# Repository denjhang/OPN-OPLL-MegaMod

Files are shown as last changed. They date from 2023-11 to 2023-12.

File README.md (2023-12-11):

# OPN-OPLL-MegaMod
 OPN+OPLL MegaMod, the latest hardware version has passed hardware verification
 
# 2023.11.25
OPN+OPLL MegaMod v0.3 have passed hardware testing and all functions have been verified. The old version has many problems and is not recommended.  
## OPN+OPLL MegaMod v0.3 includes the following features:
1. OPN and OPLL chips can support playing VGM music of PC-9801-26K, MSX-Music, ZX-Spectrum, and Atari ST. Software driver support provided by natalie.  
2. A typical dual op amp driven by a single 5V (take NE5532 as an example), it works well and sounds loud. It is especially effective for the sound amplification function of OPLL.  
3. Independent volume adjustment knob. Supports adjusting the volume of OPN and SSG, as well as the overall volume of the mixer. The volume of OPLL cannot be adjusted because the volume of OPLL itself is too small. This function is completely normal, and the volumes of each channel will not interfere with each other when adjusting the volume.  
4. SSG can be configured with stereo sound. Use three three-position toggle switches to independently control the stereo channels of each SSG. This function is completely normal and will not affect the volume of OPN and OPLL.
5. SSG stereo mixing circuit. This part is based on the ZX-Spectrum's golden ratio mixing circuit, but I modified the resistor values to provide a more stereo effect.  
6. OPN and OPLL monophonic mixing circuit. Since there is no such combination of using OPN.FM+OPLL at the same time, OPN and OPLL configurable stereo make little sense. A mono mix is used here, which means the left and right channels sound the same.  
7. Compatible with OPLL cloning chip. Just remove the pull-down resistors of the MO and RO analog audio tree pool of YM2413.  
8. Compatible with U3567, UM3567, YM2413-F and YM2413B-F, using a simple conversion board to implement.  

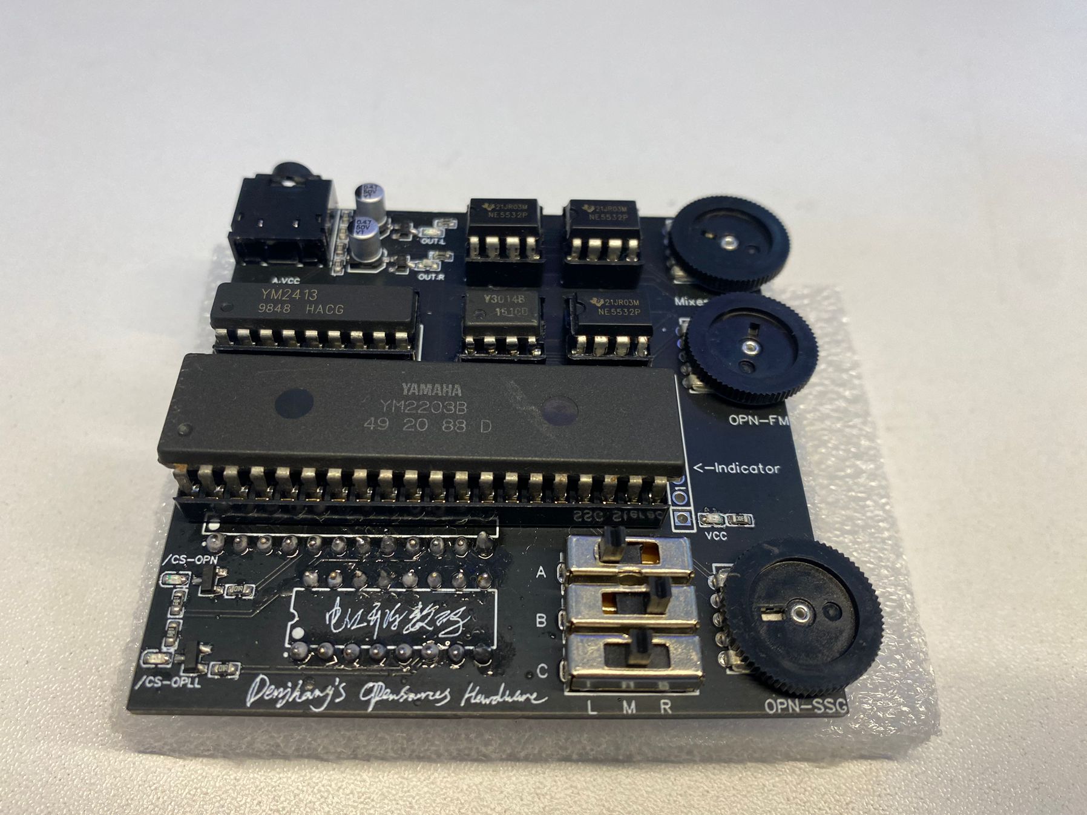
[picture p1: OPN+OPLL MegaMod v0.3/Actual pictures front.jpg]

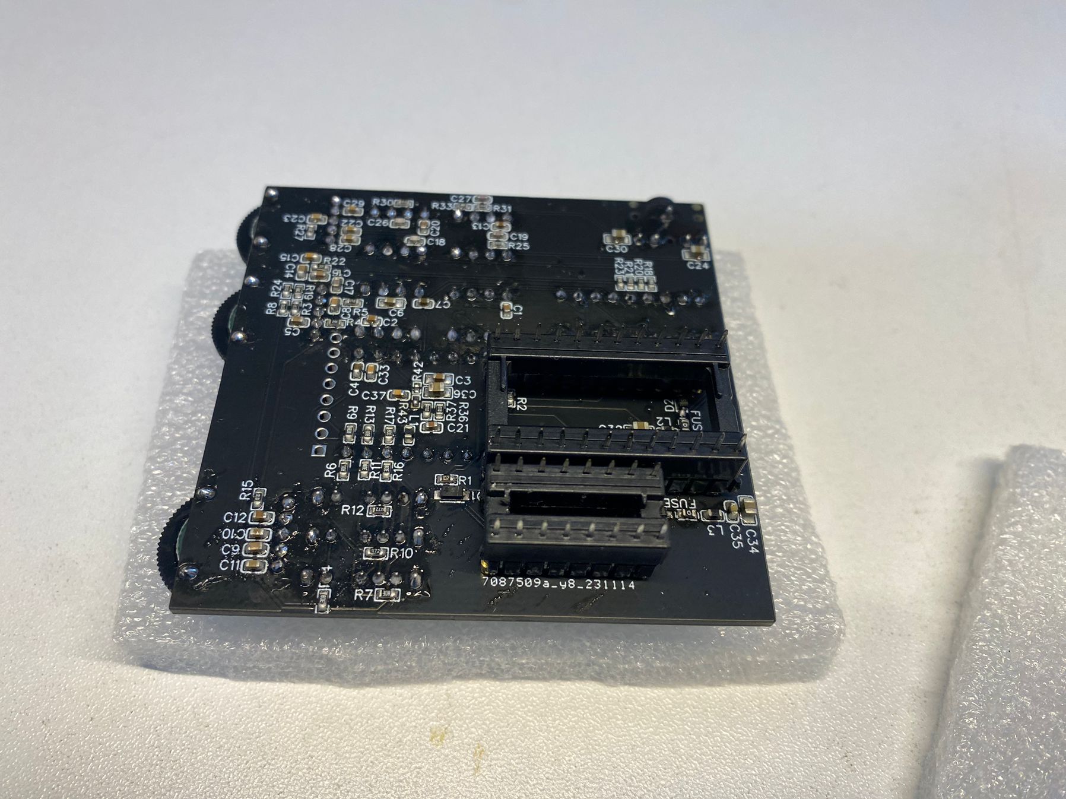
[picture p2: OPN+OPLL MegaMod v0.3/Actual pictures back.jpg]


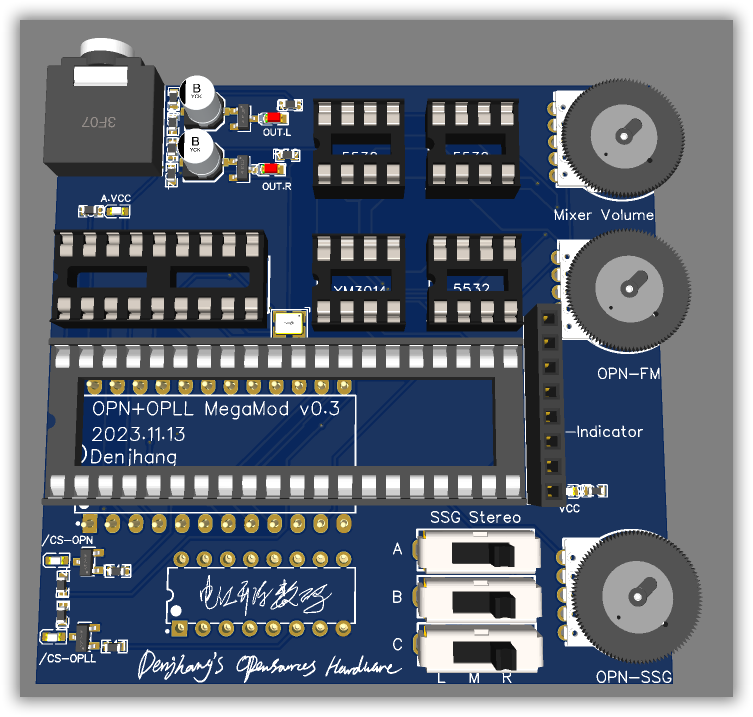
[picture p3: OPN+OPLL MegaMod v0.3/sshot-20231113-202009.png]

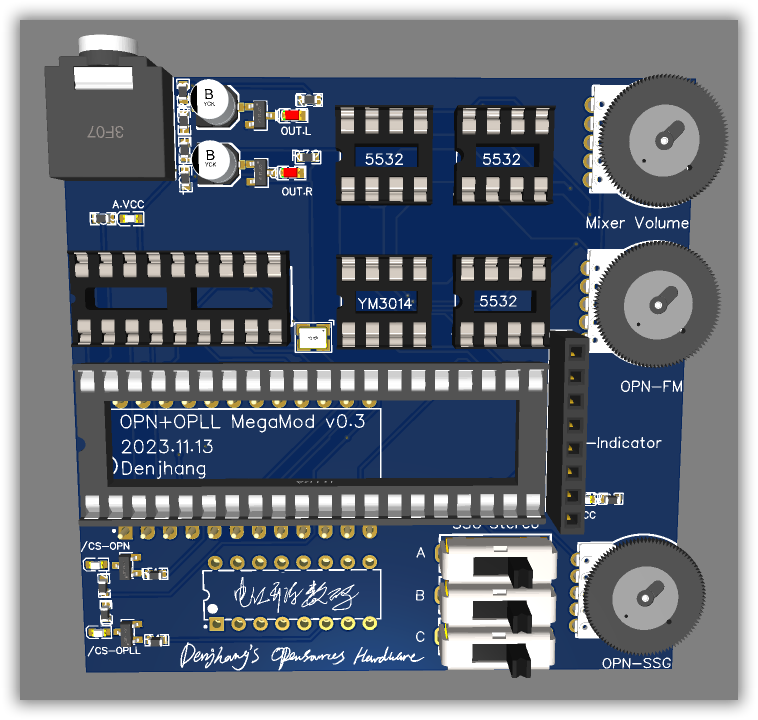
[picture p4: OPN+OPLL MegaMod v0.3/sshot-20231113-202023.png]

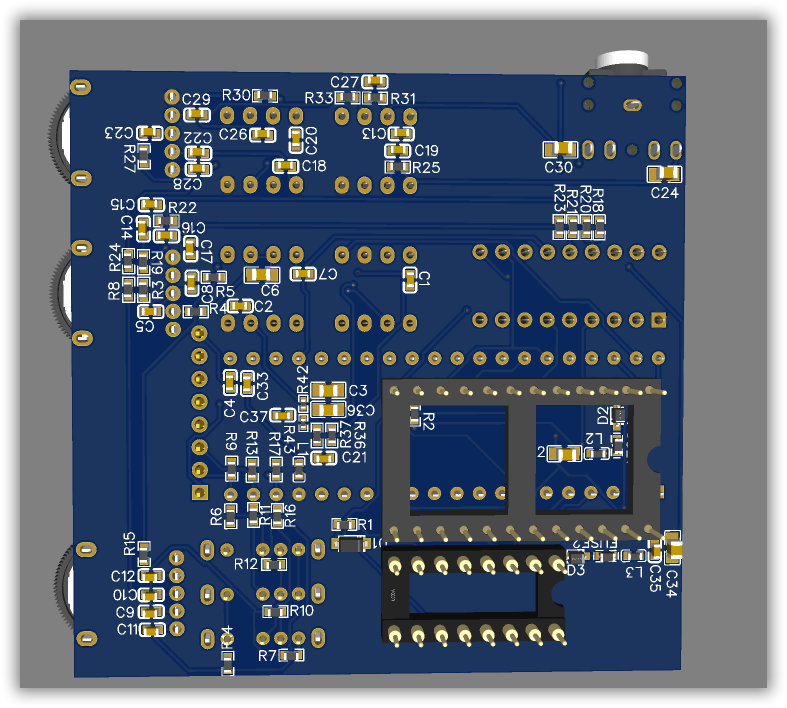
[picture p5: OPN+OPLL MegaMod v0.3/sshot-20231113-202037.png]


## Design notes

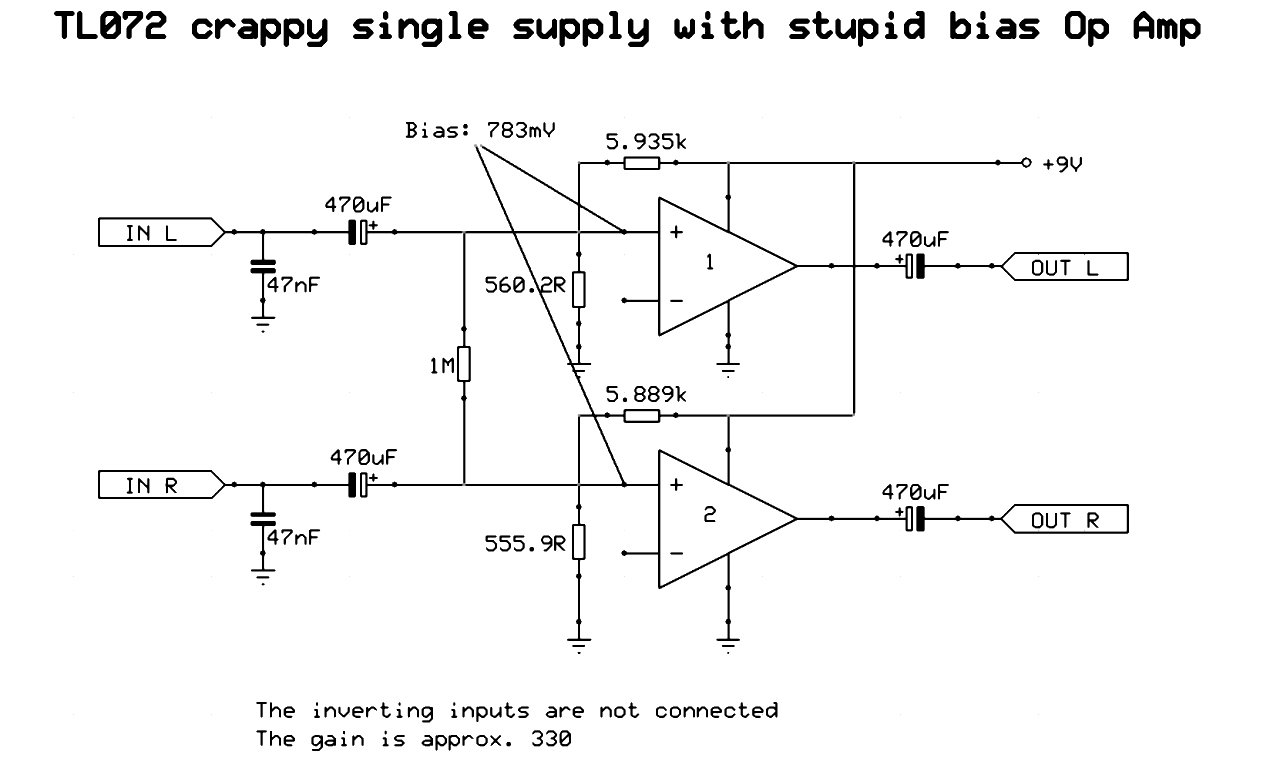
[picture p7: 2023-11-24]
资料2/TL072__Schematic_01.png

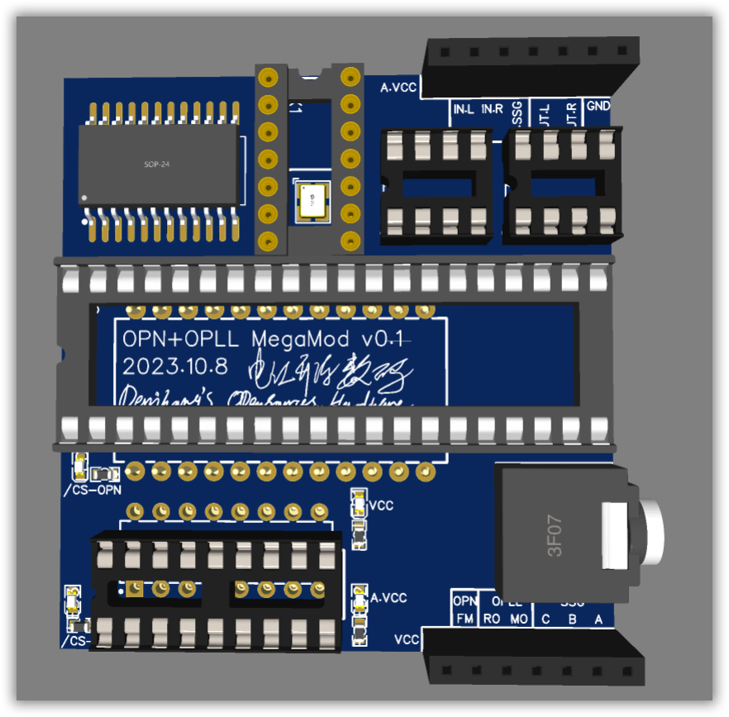
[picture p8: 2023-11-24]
pics/sshot-20231008-172234.png

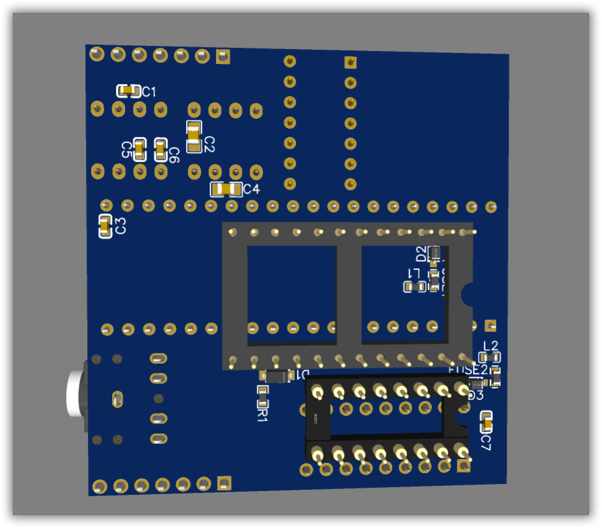
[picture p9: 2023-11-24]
pics/sshot-20231008-172720.png

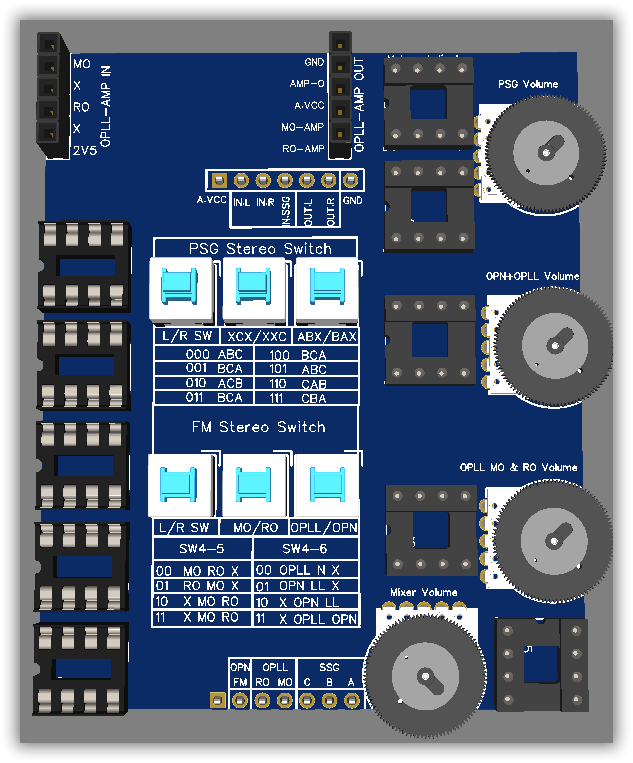
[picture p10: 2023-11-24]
OPN+OPLL AMP v0.1/pics/sshot-20231009-220135.png

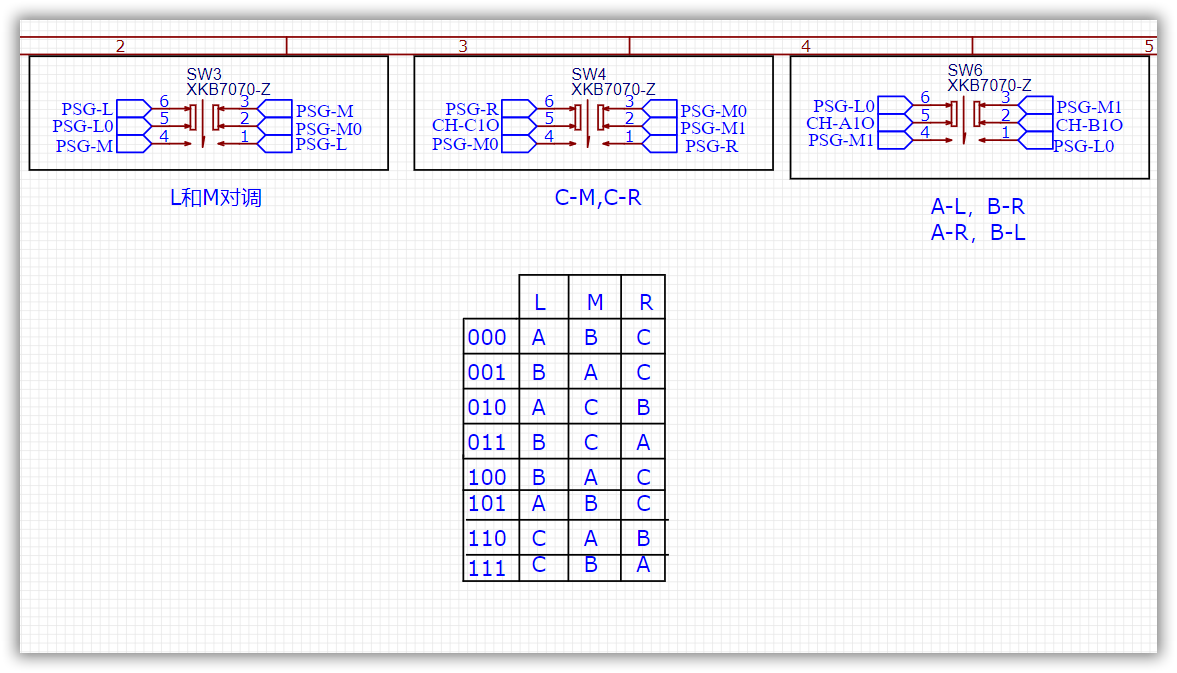
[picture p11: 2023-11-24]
pics/sshot-20231009-154045.png

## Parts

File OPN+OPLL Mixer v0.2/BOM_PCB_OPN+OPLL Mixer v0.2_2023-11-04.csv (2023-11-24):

ID | Name | Designator | Footprint | Quantity | Manufacturer Part | Manufacturer | Supplier | Supplier Part | Price
1 | 2k7 | R11,R9,R14,R17,R25,R27,R30,R32,R33,R34,R16,R18 | R0603 | 12
2 | 100k | R44,R6,R43,R1 | R0603 | 4
3 | PZ254V-11-07P | H1,H2 | HDR-TH_7P-P2.54-V-M | 2 | PZ254V-11-07P | XFCN(兴飞) | LCSC | C492406 | 0.2121
4 | 100Ω | L1 | L0603 | 1 | CBW160808U102T | FH | LCSC | C50069 | 0.0296
5 | 1N5819WS | D1 | SOD-323_L1.8-W1.3-LS2.5-RD | 1 | 1N5819WS | Hottech(合科泰) | LCSC | C191023 | 0.0759
6 | PPTC0.5A/24V 自恢复保险丝-0603 | FUSE1 | F0603 | 1 | PPTC0.5A/24V 自恢复保险丝-0603 | null | LCSC | C9900007586
7 | 2k2 | R26,R31,R5,R10,R15,R3 | R0603 | 6
8 | 4k7 | R28,R29,R12,R13 | R0603 | 4
9 | 120p | C9,C13,C22,C24,C1,C5 | C0603 | 6
10 | 1u | C10,C15,C2,C7 | C0603 | 4
11 | 1u | C11,C16,C3,C8 | C0805 | 4
12 | 22pf | C12,C14 | C0603 | 2
13 | 47p | C17 | C0603 | 1
14 | 2.2u | C18,C19 | C0603 | 2
15 | 4.7u | C20,C21 | C0603 | 2
16 | 47u | C23,C25 | C0805 | 2
17 | 100u | C26 | C1206 | 1
18 | 20k | R4,R7,R36,R37,R39,R40,R41 | R0603 | 7
19 | 22k | R8,R20,R22,R24,R2 | R0603 | 5
20 | 51k | R19,R21,R23,R35,R38 | R0603 | 5
21 | 1.5n | C4,C6 | C0603 | 2
22 | SS-22D07 | SW7 | SW-TH_SS-22D07 | 1 | SS-22D07 | ReliaPro | LCSC | C34982 | 0.241
23 | 10k | R42 | R0603 | 1
24 | HX SS13D07VG3-DJ | SW1,SW2,SW3,SW4,SW5,SW6 | SW-TH_SS13D07VG4 | 6 | HX SS13D07VG3 | hanxia(韩下) | LCSC | C5149830 | 0.1776
25 | NE5532-DJ | U3,U4,U5,U6 | DIP-8-DJ | 4 | NE5532P | TI | LCSC | C5326 | 2.91
26 | PM254-1-08-Z-8.5 | U1,U2 | HDR-TH_8P-P2.54-V-F | 2 | PM254-1-08-Z-8.5 | HCTL(华灿天禄) | LCSC | C2897371 | 0.8039
27 | 圆盘双联电位器10K | RV1,RV2,RV4,RV3 | RES-TH_RK10J12E002L | 4
28 | LED0603 | LED1,LED2 | LED0603-RD | 2 | GBG-C192KRKT | GBG | LCSC | C2892154 | 0.0219

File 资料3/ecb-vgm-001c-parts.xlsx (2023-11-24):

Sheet: Sheet1
"Ref","Qnty","Value","Cmp name","Footprint","Description","Vendor"
"C1, C2, C3, C4, C7, C8, C10, C18, C19, C22, C23, C28, C29, C50, ","14","0.1uF","C","Capacitor_THT:C_Disc_D7.0mm_W2.5mm_P5.00mm"," | Unp | olarized capacitor",""
"C5, C20, C21, C34, C35, ","5","470uF","CP","Capacitor_THT:CP_Radial_D8.0mm_P2.50mm","Polarized capacitor",""
"C6, ","1","100uF","CP","Capacitor_THT:CP_Radial_D5.0mm_P2.50mm","Polarized capacitor",""
"C24, C25, ","2","100uF","CP","Capacitor_THT:CP_Radial_D8.0mm_P2.50mm","Polarized capacitor",""
"C26, C27, C36, C37, C39, C41, ","6","10uF","C","Capacitor_THT:CP_Radial_D5.0mm_P2.50mm","Unpolarized capacitor",""
"C30, C31, ","2","470pF","C","Capacitor_THT:C_Disc_D3.8mm_W2.6mm_P2.50mm","Unpolarized capacitor",""
"C32, C33, ","2","1uF","C","Capacitor_THT:C_Disc_D7.0mm_W2.5mm_P5.00mm","Unpolarized capacitor",""
"C38, C46, ","2","220pF","C","Capacitor_THT:C_Disc_D3.8mm_W2.6mm_P2.50mm","Unpolarized capacitor",""
"C40, C47, ","2","1uF","C","Capacitor_THT:CP_Radial_D5.0mm_P2.50mm","Unpolarized capacitor",""
"C42, C43, C44, C45, ","4","5.6nF","C","Capacitor_THT:C_Disc_D3.8mm_W2.6mm_P2.50mm","Unpolarized capacitor",""
"CX1, CX2, ","2","0.1uF","C","Capacitor_THT:C_Disc_D7.0mm_W2.5mm_P5.00mm","Unpolarized capacitor",""
"H1, ","1","MountingHole","MountingHole","MountingHole:MountingHole_5mm","Mounting Hole without connection",""
"J1, ","1","Barrel_Jack","Barrel_Jack","Connector_BarrelJack:BarrelJack_Horizontal","DC Barrel Jack",""
"J3, ","1","Conn_01x04","Conn_01x04","TerminalBlock:TerminalBlock_bornier-4_P5.08mm","Generic connector, single row, 01x04, script | ge | nerated (kicad-library-utils/schlib/autogen/connector/)",""
"JP1, ","1","Jumper_3_Open","Jumper_3_Open","Connector_PinHeader_2.54mm:PinHeader_1x03_P2.54mm_Vertical","Jumper, 3-pole, both ope | n", | ""
"L1, L2, ","2","33uH","INDUCTOR","Inductor_THT:L_Axial_L6.6mm_D2.7mm_P10.16mm_Horizontal_Vishay_IM-2","Inductor symbol for simulat | ion | only",""
"R1, R3, R4, R5, R6, R7, ","6","2K2","R","Resistor_THT:R_Axial_DIN0207_L6.3mm_D2.5mm_P10.16mm_Horizontal","Resistor",""
"R2, R13, ","2","51K","R","Resistor_THT:R_Axial_DIN0207_L6.3mm_D2.5mm_P10.16mm_Horizontal","Resistor",""
"R8, R9, R14, R15, R16, R17, ","6","10K","R","Resistor_THT:R_Axial_DIN0207_L6.3mm_D2.5mm_P10.16mm_Horizontal","Resistor",""
"R10, R11, ","2","10R","R","Resistor_THT:R_Axial_DIN0207_L6.3mm_D2.5mm_P10.16mm_Horizontal","Resistor",""
"R12, R20, ","2","47K","R","Resistor_THT:R_Axial_DIN0207_L6.3mm_D2.5mm_P10.16mm_Horizontal","Resistor",""
"R18, R19, ","2","33K","R","Resistor_THT:R_Axial_DIN0207_L6.3mm_D2.5mm_P10.16mm_Horizontal","Resistor",""
"RN1, ","1","22K","R_Network08","Resistor_THT:R_Array_SIP9","8 resistor network, star topology, bussed resistors, small symbol",""
"RV1, ","1","10K","R_POT_Dual","Potentiometer_THT:Potentiometer_Alps_RK097_Dual_Horizontal","Dual potentiometer",""
"RV2, RV3, ","2","10K","R_POT_TRIM","Potentiometer_THT:Potentiometer_Bourns_3339P_Vertical","Trim-potentiometer",""
"SW1, ","1","ADDR","Conn_02x06_Odd_Even","Connector_PinHeader_2.54mm:PinHeader_2x06_P2.54mm_Vertical","Generic connector, double r | ow, | 02x06, odd/even pin numbering scheme (row 1 odd numbers, row 2 even numbers), script generated (kicad-library-utils/schlib/autogen/connector/)",""
"SW3, ","1","N8VEM/KONTRON","Conn_01x03","Jumper:SolderJumper-3_P1.3mm_Open_RoundedPad1.0x1.5mm_NumberLabels","Generic connector, | sin | gle row, 01x03, script generated (kicad-library-utils/schlib/autogen/connector/)",""
"U1, ","1","74LS245","74LS245","Package_DIP:DIP-20_W7.62mm","Octal BUS Transceivers, 3-State outputs",""
"U2, U8, ","2","74LS241","74LS241","Package_DIP:DIP-20_W7.62mm","Octal Buffer and Line Driver With 3-State Output, complementary e | nab | les, non-inverting outputs",""
"U3, ","1","74LS688","74LS688","Package_DIP:DIP-20_W7.62mm","8-bit magnitude comparator",""
"U4, ","1","YM2612","YM2612-Audio","Package_DIP:DIP-24_W15.24mm","",""
"U5, ","1","TL072","TL072","Package_DIP:DIP-8_W7.62mm","Dual Low-Noise JFET-Input Operational Amplifiers, DIP-8/SOIC-8",""
"U6, ","1","74LS74","74LS74","Package_DIP:DIP-14_W7.62mm","Dual D Flip-flop, Set & Reset",""
"U10, ","1","74LS139","74LS139","Package_DIP:DIP-16_W7.62mm","Dual Decoder 1 of 4, Active low outputs",""
"U18, U19, ","2","SN76489","SN76489","Package_DIP:DIP-16_W7.62mm","",""
"U20, ","1","C96ABC","C96ABC","library:C96ABCMC","Connector Europe, 96 contacts, ranges A,B,C",""
"U21, U22, ","2","LM386","LM386","Package_DIP:DIP-8_W7.62mm","Low Voltage Audio Power Amplifier, DIP-8/SOIC-8/SSOP-8",""
"X1, ","1","3.57595Mhz","CXO_DIP8","Oscillator:Oscillator_DIP-8","Crystal Clock Oscillator, DIP8-style metal package",""
"X2, ","1","7.6Mhz","CXO_DIP8","Oscillator:Oscillator_DIP-8","Crystal Clock Oscillator, DIP8-style metal package",""

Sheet: Sheet2
Ref | Qnty | Value | Cmp name | Footprint | Description | Vendor
C1, C2, C3, C4, C7, C8, C10, C18, C19, C22, C23, C28, C29, C50, | 14 | 0.1uF | C | Capacitor_THT:C_Disc_D7.0mm_W2.5mm_P5.00mm | Unpolarized capacitor
C5, C20, C21, C34, C35, | 5 | 470uF | CP | Capacitor_THT:CP_Radial_D8.0mm_P2.50mm | Polarized capacitor
C6, | 1 | 100uF | CP | Capacitor_THT:CP_Radial_D5.0mm_P2.50mm | Polarized capacitor
C24, C25, | 2 | 100uF | CP | Capacitor_THT:CP_Radial_D8.0mm_P2.50mm | Polarized capacitor
C26, C27, C36, C37, C39, C41, | 6 | 10uF | C | Capacitor_THT:CP_Radial_D5.0mm_P2.50mm | Unpolarized capacitor
C30, C31, | 2 | 470pF | C | Capacitor_THT:C_Disc_D3.8mm_W2.6mm_P2.50mm | Unpolarized capacitor
C32, C33, | 2 | 1uF | C | Capacitor_THT:C_Disc_D7.0mm_W2.5mm_P5.00mm | Unpolarized capacitor
C38, C46, | 2 | 220pF | C | Capacitor_THT:C_Disc_D3.8mm_W2.6mm_P2.50mm | Unpolarized capacitor
C40, C47, | 2 | 1uF | C | Capacitor_THT:CP_Radial_D5.0mm_P2.50mm | Unpolarized capacitor
C42, C43, C44, C45, | 4 | 5.6nF | C | Capacitor_THT:C_Disc_D3.8mm_W2.6mm_P2.50mm | Unpolarized capacitor
CX1, CX2, | 2 | 0.1uF | C | Capacitor_THT:C_Disc_D7.0mm_W2.5mm_P5.00mm | Unpolarized capacitor
H1, | 1 | MountingHole | MountingHole | MountingHole:MountingHole_5mm | Mounting Hole without connection
J1, | 1 | Barrel_Jack | Barrel_Jack | Connector_BarrelJack:BarrelJack_Horizontal | DC Barrel Jack
J3, | 1 | Conn_01x04 | Conn_01x04 | TerminalBlock:TerminalBlock_bornier-4_P5.08mm | Generic connector, single row, 01x04, script generated (kicad-library-utils/schlib/autogen/connector/)
JP1, | 1 | Jumper_3_Open | Jumper_3_Open | Connector_PinHeader_2.54mm:PinHeader_1x03_P2.54mm_Vertical | Jumper, 3-pole, both open
L1, L2, | 2 | 33uH | INDUCTOR | Inductor_THT:L_Axial_L6.6mm_D2.7mm_P10.16mm_Horizontal_Vishay_IM-2 | Inductor symbol for simulation only
R1, R3, R4, R5, R6, R7, | 6 | 2K2 | R | Resistor_THT:R_Axial_DIN0207_L6.3mm_D2.5mm_P10.16mm_Horizontal | Resistor
R2, R13, | 2 | 51K | R | Resistor_THT:R_Axial_DIN0207_L6.3mm_D2.5mm_P10.16mm_Horizontal | Resistor
R8, R9, R14, R15, R16, R17, | 6 | 10K | R | Resistor_THT:R_Axial_DIN0207_L6.3mm_D2.5mm_P10.16mm_Horizontal | Resistor
R10, R11, | 2 | 10R | R | Resistor_THT:R_Axial_DIN0207_L6.3mm_D2.5mm_P10.16mm_Horizontal | Resistor
R12, R20, | 2 | 47K | R | Resistor_THT:R_Axial_DIN0207_L6.3mm_D2.5mm_P10.16mm_Horizontal | Resistor
R18, R19, | 2 | 33K | R | Resistor_THT:R_Axial_DIN0207_L6.3mm_D2.5mm_P10.16mm_Horizontal | Resistor
RN1, | 1 | 22K | R_Network08 | Resistor_THT:R_Array_SIP9 | 8 resistor network, star topology, bussed resistors, small symbol
RV1, | 1 | 10K | R_POT_Dual | Potentiometer_THT:Potentiometer_Alps_RK097_Dual_Horizontal | Dual potentiometer
RV2, RV3, | 2 | 10K | R_POT_TRIM | Potentiometer_THT:Potentiometer_Bourns_3339P_Vertical | Trim-potentiometer
SW1, | 1 | ADDR | Conn_02x06_Odd_Even | Connector_PinHeader_2.54mm:PinHeader_2x06_P2.54mm_Vertical | Generic connector, double row, 02x06, odd/even pin numbering scheme (row 1 odd numbers, row 2 even numbers), script generated (kicad-library-utils/schlib/autogen/connector/)
SW3, | 1 | N8VEM/KONTRON | Conn_01x03 | Jumper:SolderJumper-3_P1.3mm_Open_RoundedPad1.0x1.5mm_NumberLabels | Generic connector, single row, 01x03, script generated (kicad-library-utils/schlib/autogen/connector/)
U1, | 1 | 74LS245 | 74LS245 | Package_DIP:DIP-20_W7.62mm | Octal BUS Transceivers, 3-State outputs
U2, U8, | 2 | 74LS241 | 74LS241 | Package_DIP:DIP-20_W7.62mm | Octal Buffer and Line Driver With 3-State Output, complementary enables, non-inverting outputs
U3, | 1 | 74LS688 | 74LS688 | Package_DIP:DIP-20_W7.62mm | 8-bit magnitude comparator
U4, | 1 | YM2612 | YM2612-Audio | Package_DIP:DIP-24_W15.24mm
U5, | 1 | TL072 | TL072 | Package_DIP:DIP-8_W7.62mm | Dual Low-Noise JFET-Input Operational Amplifiers, DIP-8/SOIC-8
U6, | 1 | 74LS74 | 74LS74 | Package_DIP:DIP-14_W7.62mm | Dual D Flip-flop, Set & Reset
U10, | 1 | 74LS139 | 74LS139 | Package_DIP:DIP-16_W7.62mm | Dual Decoder 1 of 4, Active low outputs
U18, U19, | 2 | SN76489 | SN76489 | Package_DIP:DIP-16_W7.62mm
U20, | 1 | C96ABC | C96ABC | library:C96ABCMC | Connector Europe, 96 contacts, ranges A,B,C
U21, U22, | 2 | LM386 | LM386 | Package_DIP:DIP-8_W7.62mm | Low Voltage Audio Power Amplifier, DIP-8/SOIC-8/SSOP-8
X1, | 1 | 3.57595Mhz | CXO_DIP8 | Oscillator:Oscillator_DIP-8 | Crystal Clock Oscillator, DIP8-style metal package
X2, | 1 | 7.6Mhz | CXO_DIP8 | Oscillator:Oscillator_DIP-8 | Crystal Clock Oscillator, DIP8-style metal package

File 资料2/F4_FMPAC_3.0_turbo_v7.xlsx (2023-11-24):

Reference | Value | Footprint | Datasheet | Cdad
C1, C2 | 2.2uF25v | MSXmakers:CP_tumbado | ~ | 2
C3, C4, C22, C23 | 22pF | Capacitor_THT:C_Disc_D4.3mm_W1.9mm_P5.00mm | -- valores mixtos -- | 4
C5, C6 | 47uF 16v | MSXmakers:CP_tumbado | ~ | 2
C7, C12 | 1uF 25v | MSXmakers:CP_tumbado | ~ | 2
C8, C10, C11, C13, C15, C17, C18 | 100nF | Capacitor_THT:C_Disc_D4.3mm_W1.9mm_P5.00mm |  | 7
C9 | 10uF 16V | MSXmakers:CP_tumbado | ~ | 1
C14, C24 | 330pF | Capacitor_THT:C_Disc_D4.3mm_W1.9mm_P5.00mm | -- valores mixtos -- | 2
C16 | 68pF | Capacitor_THT:C_Disc_D4.3mm_W1.9mm_P5.00mm |  | 1
CN1 | DIP40 MB CONN | Package_DIP:DIP-40_W15.24mm_Socket |  | 1
CN2 | DIP8 MB CONN | Package_DIP:DIP-8_W7.62mm_Socket | http://ww1.microchip.com/downloads/en/DeviceDoc/21314g.pdf | 1
D1, D2 | 1N4148 | Diode_THT:D_DO-35_SOD27_P7.62mm_Horizontal | -- valores mixtos -- | 2
D3 | LED | LED_THT:LED_D3.0mm | ~ | 1
D4 | LED 3mm | LED_THT:LED_D3.0mm | ~ | 1
J1 | clock_sel MB/JP | Connector_PinSocket_2.54mm:PinSocket_1x02_P2.54mm_Vertical | ~ | 1
J2 | slot clock | Connector_PinSocket_2.54mm:PinSocket_1x02_P2.54mm_Vertical | ~ | 1
J3 | Clocksel | Connector_PinHeader_2.54mm:PinHeader_1x03_P2.54mm_Vertical | ~ | 1
JP1 | Conn_01x05 | MSXmakers:Eletechsup_DD1718PA | ~ | 1
Q1 | BS170 | Package_TO_SOT_THT:TO-92L | https://www.onsemi.com/pub/Collateral/BS170-D.PDF | 1
R1, R2, R9, R10 | 22k | Resistor_THT:R_Axial_DIN0204_L3.6mm_D1.6mm_P7.62mm_Horizontal |  | 4
R3, R22 | 100k | Resistor_THT:R_Axial_DIN0204_L3.6mm_D1.6mm_P7.62mm_Horizontal | -- valores mixtos -- | 2
R4-R8 | 2k2 | Resistor_THT:R_Axial_DIN0204_L3.6mm_D1.6mm_P7.62mm_Horizontal |  | 5
R11 | 68R | Resistor_THT:R_Axial_DIN0204_L3.6mm_D1.6mm_P7.62mm_Horizontal |  | 1
R12, R13 | 100R | Resistor_THT:R_Axial_DIN0204_L3.6mm_D1.6mm_P7.62mm_Horizontal |  | 2
R14 | 1k | Resistor_THT:R_Axial_DIN0204_L3.6mm_D1.6mm_P7.62mm_Horizontal |  | 1
R15 | 4k7 | Resistor_THT:R_Axial_DIN0204_L3.6mm_D1.6mm_P7.62mm_Horizontal |  | 1
R16, R24 | 560R | Resistor_THT:R_Axial_DIN0204_L3.6mm_D1.6mm_P7.62mm_Horizontal | -- valores mixtos -- | 2
R18 | 22K | Resistor_THT:R_Axial_DIN0204_L3.6mm_D1.6mm_P7.62mm_Horizontal | ~ | 1
R20 | 10M | Resistor_THT:R_Axial_DIN0204_L3.6mm_D1.6mm_P7.62mm_Horizontal | ~ | 1
R21 | 220R | Resistor_THT:R_Axial_DIN0204_L3.6mm_D1.6mm_P7.62mm_Horizontal | ~ | 1
R23 | 47R | Resistor_THT:R_Axial_DIN0204_L3.6mm_D1.6mm_P7.62mm_Horizontal | ~ | 1
S1 | turbo_on | Connector_PinHeader_2.54mm:PinHeader_1x02_P2.54mm_Vertical | ~ | 1
SJ3 | SJ | Connector_PinHeader_2.54mm:PinHeader_1x02_P2.54mm_Vertical |  | 1
U1 | 74HC04 | MSXmakers:DIP-14c_W7.62mm_LongPads | https://assets.nexperia.com/documents/data-sheet/74HC_HCT04.pdf | 1
U2 | 74HC153 | MSXmakers:DIP-16c_W7.62mm_Socket_LongPads | http://www.ti.com/lit/gpn/sn74LS153 | 1
U3 | 74HC175 | MSXmakers:DIP-16c_W7.62mm_Socket_LongPads | http://www.ti.com/lit/gpn/sn74LS175 | 1
U4 | YM2413 | MSXmakers:DIP-18c_W7.62mm_LongPads |  | 1
U5 | Z80 | Package_DIP:DIP-40_W15.24mm |  | 1
U6 | GAL16V8 | MSXmakers:DIP-20c_W7.62mm_Socket_LongPads |  | 1
U8 | 74LS74 | MSXmakers:DIP-14c_W7.62mm_LongPads | 74xx/74hc_hct74.pdf | 1
U9 | 74LS125 | MSXmakers:DIP-14c_W7.62mm_LongPads | http://www.ti.com/lit/gpn/sn74LS125 | 1
U10 | LM4558N | MSXmakers:DIP-8c_W7.62mm_LongPads |  | 1
VREG1 | 78L05 | Package_TO_SOT_THT:TO-92L | http://www.st.com/content/ccc/resource/technical/document/datasheet/41/4f/b3/b0/12/d4/47/88/CD00000444.pdf/files/CD00000444.pdf/jcr:content/translations/en.CD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 | 1
Y2 | HighFreq | Crystal:Crystal_HC49-U_Vertical | ~ | 1

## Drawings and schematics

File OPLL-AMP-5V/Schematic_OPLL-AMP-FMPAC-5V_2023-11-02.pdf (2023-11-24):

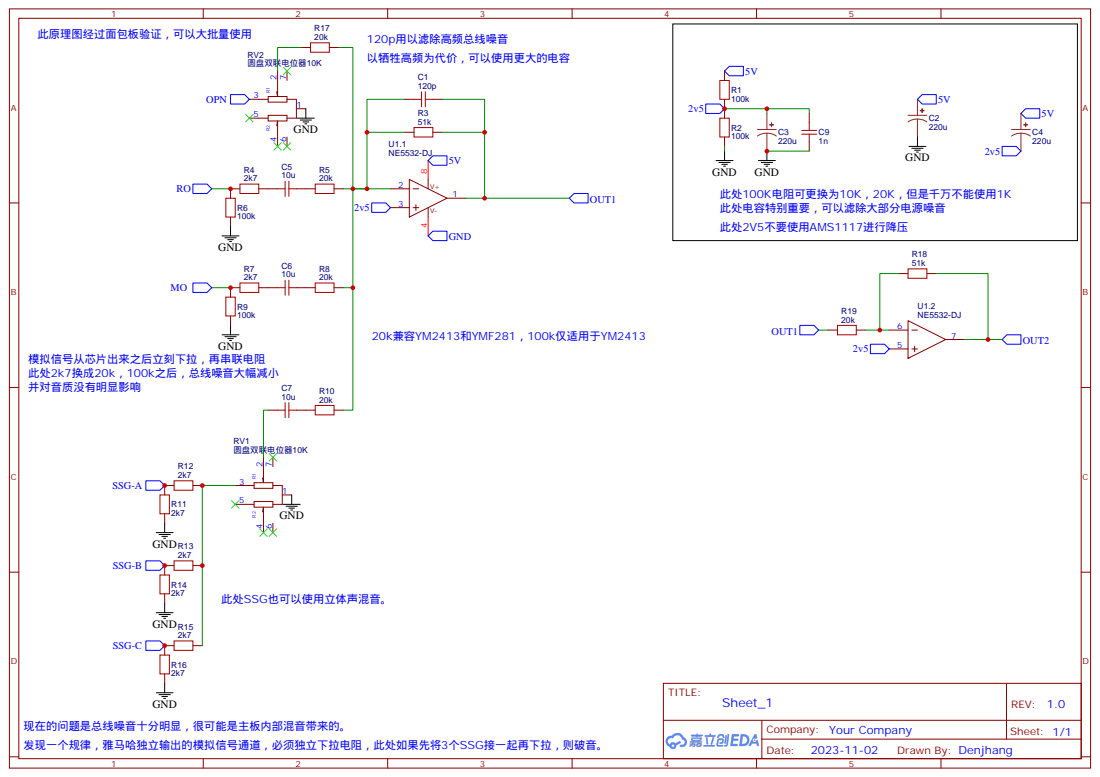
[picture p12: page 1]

现在的问题是总线噪音十分明显，很可能是主板内部混音带来的。
发现一个规律，雅马哈独立输出的模拟信号通道，必须独立下拉电阻，此处如果先将3个SSG接一起再下拉，则破音。

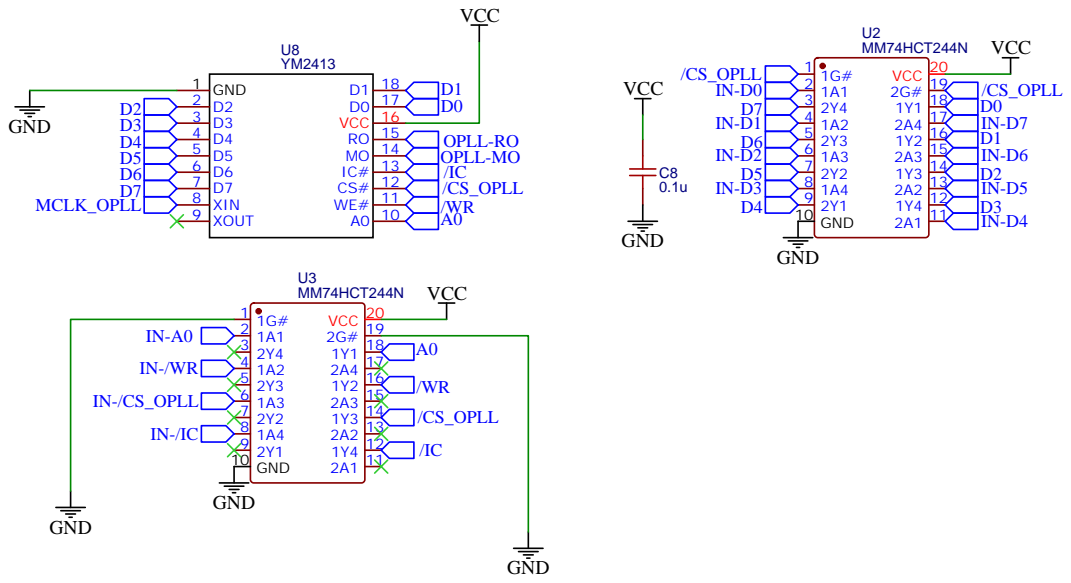
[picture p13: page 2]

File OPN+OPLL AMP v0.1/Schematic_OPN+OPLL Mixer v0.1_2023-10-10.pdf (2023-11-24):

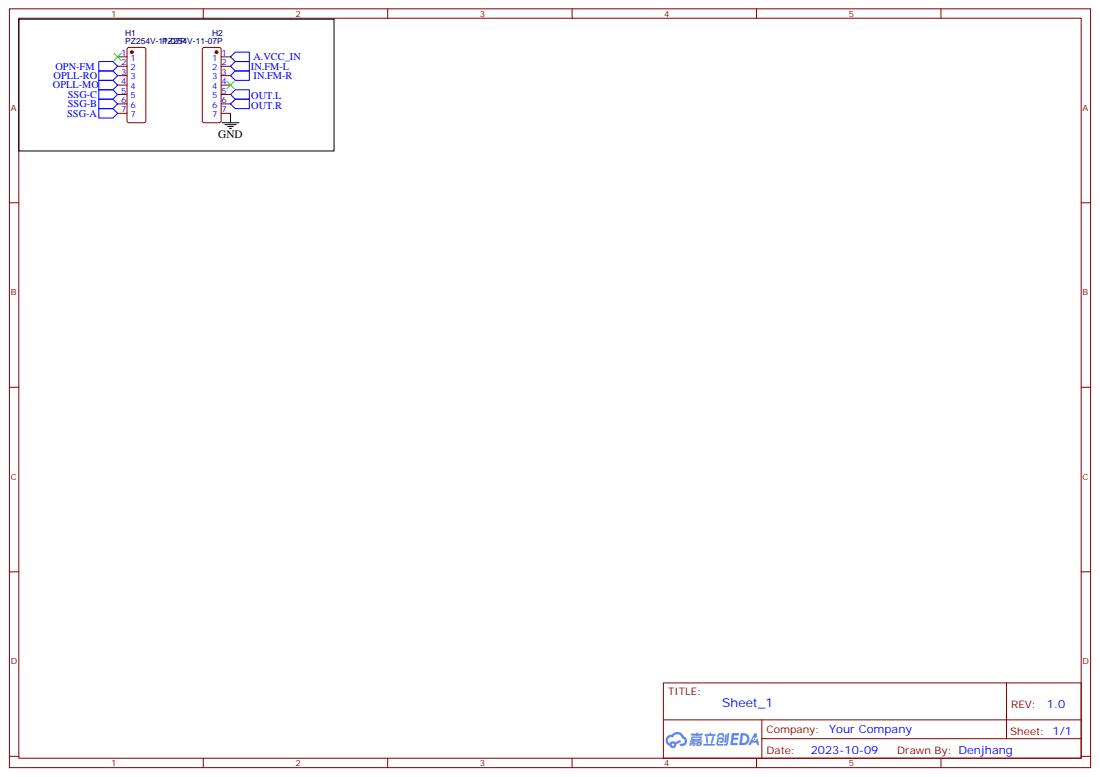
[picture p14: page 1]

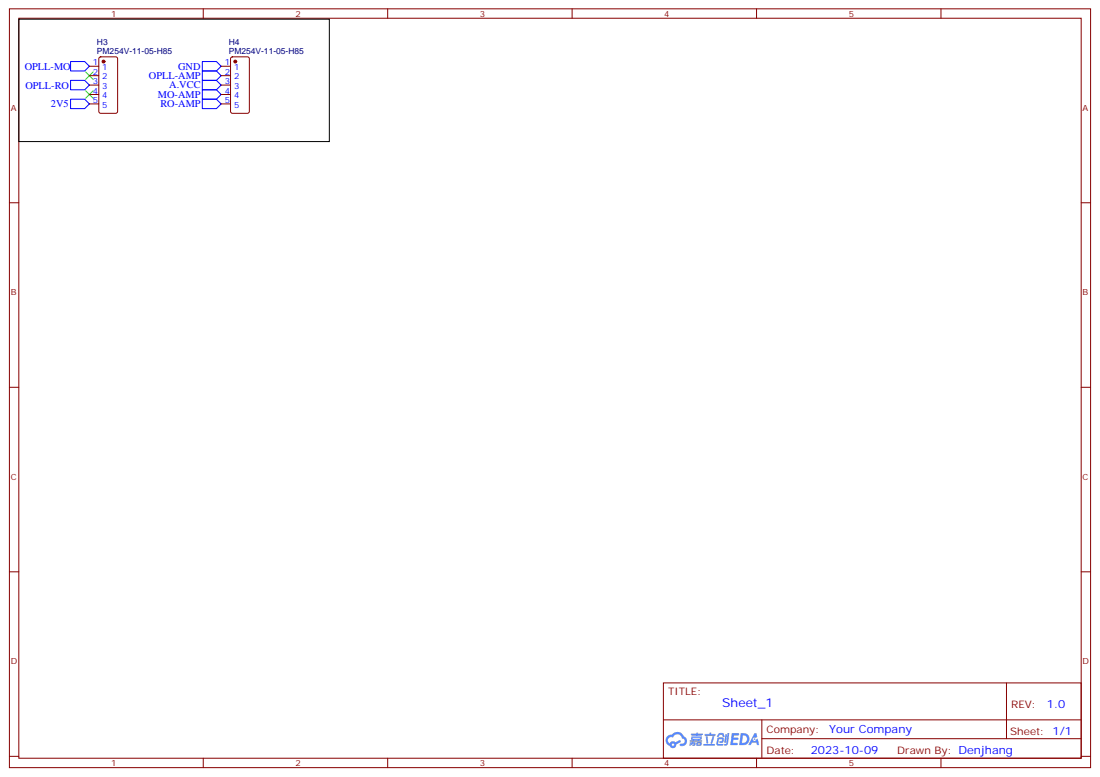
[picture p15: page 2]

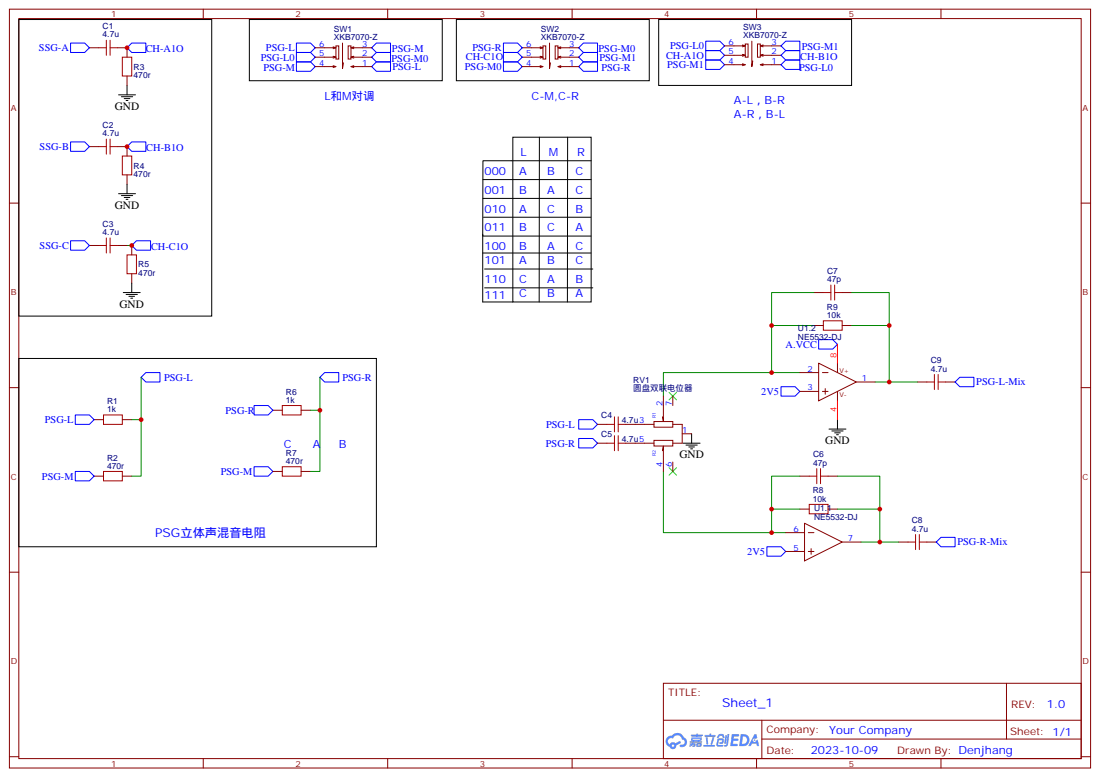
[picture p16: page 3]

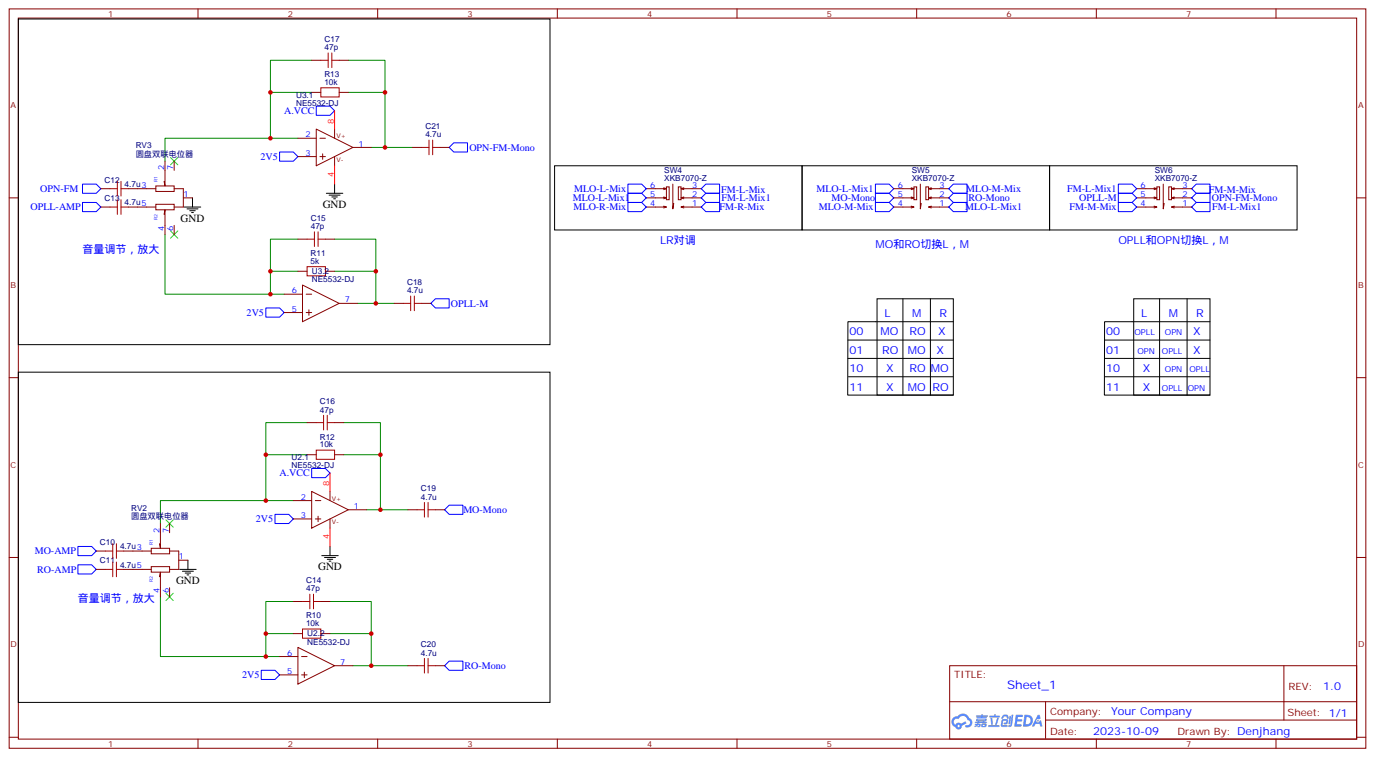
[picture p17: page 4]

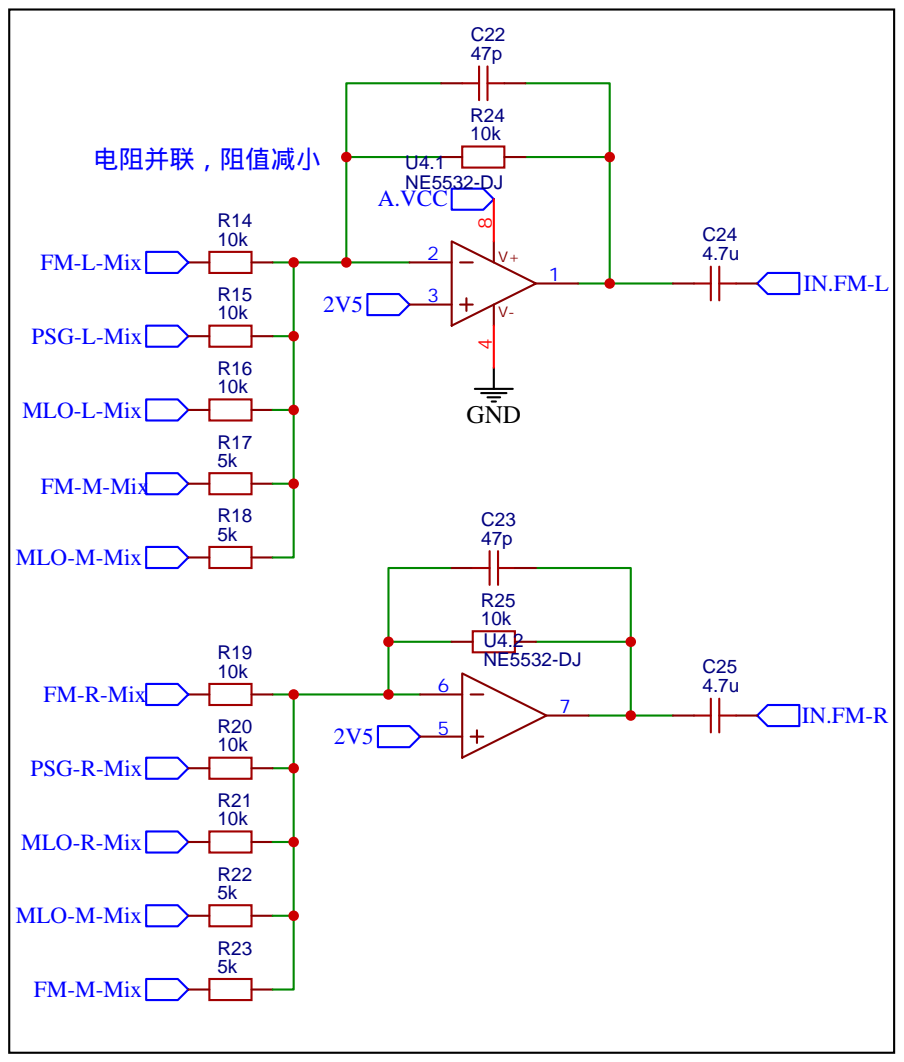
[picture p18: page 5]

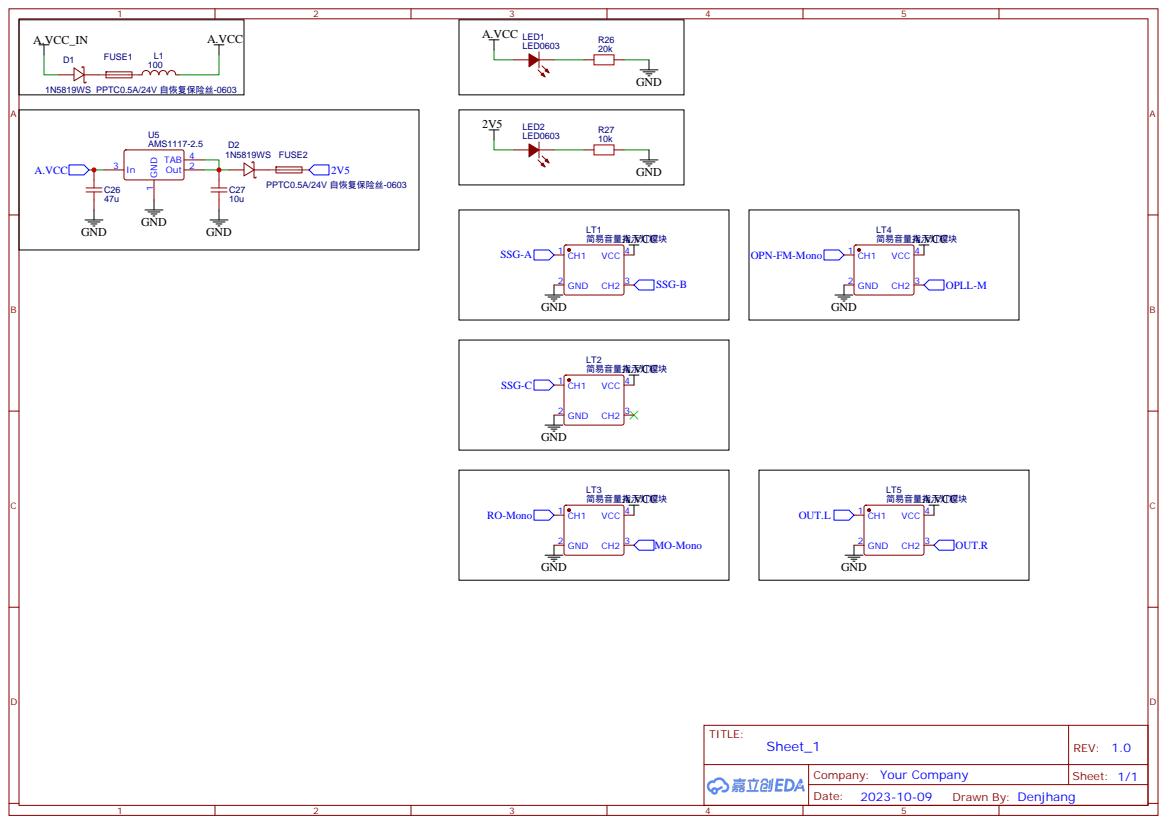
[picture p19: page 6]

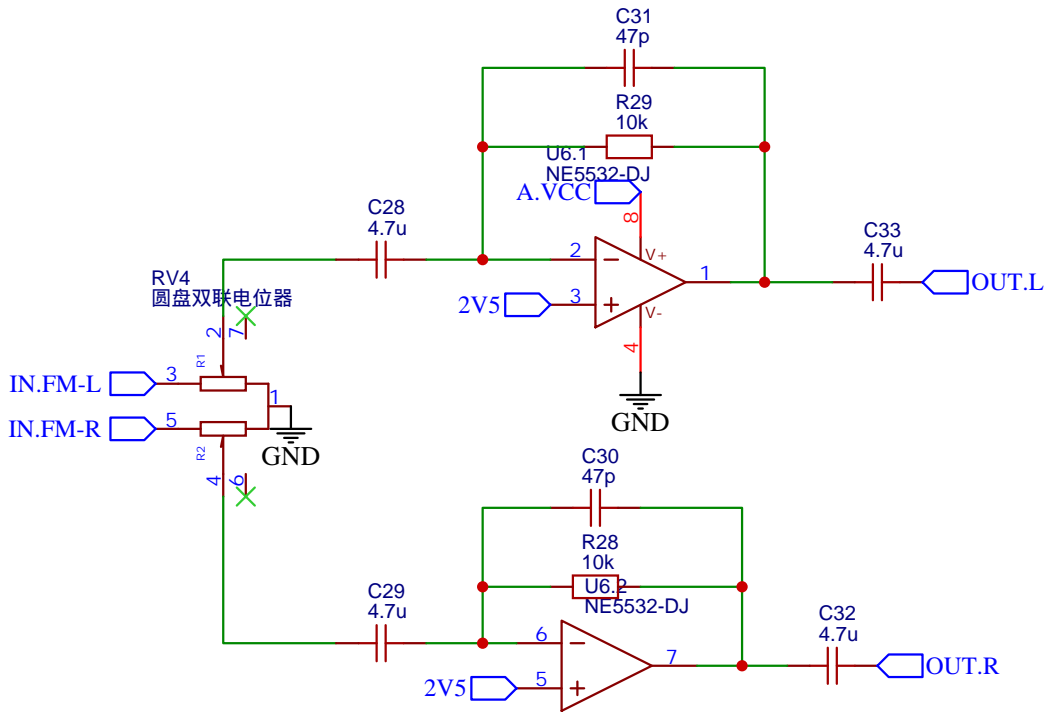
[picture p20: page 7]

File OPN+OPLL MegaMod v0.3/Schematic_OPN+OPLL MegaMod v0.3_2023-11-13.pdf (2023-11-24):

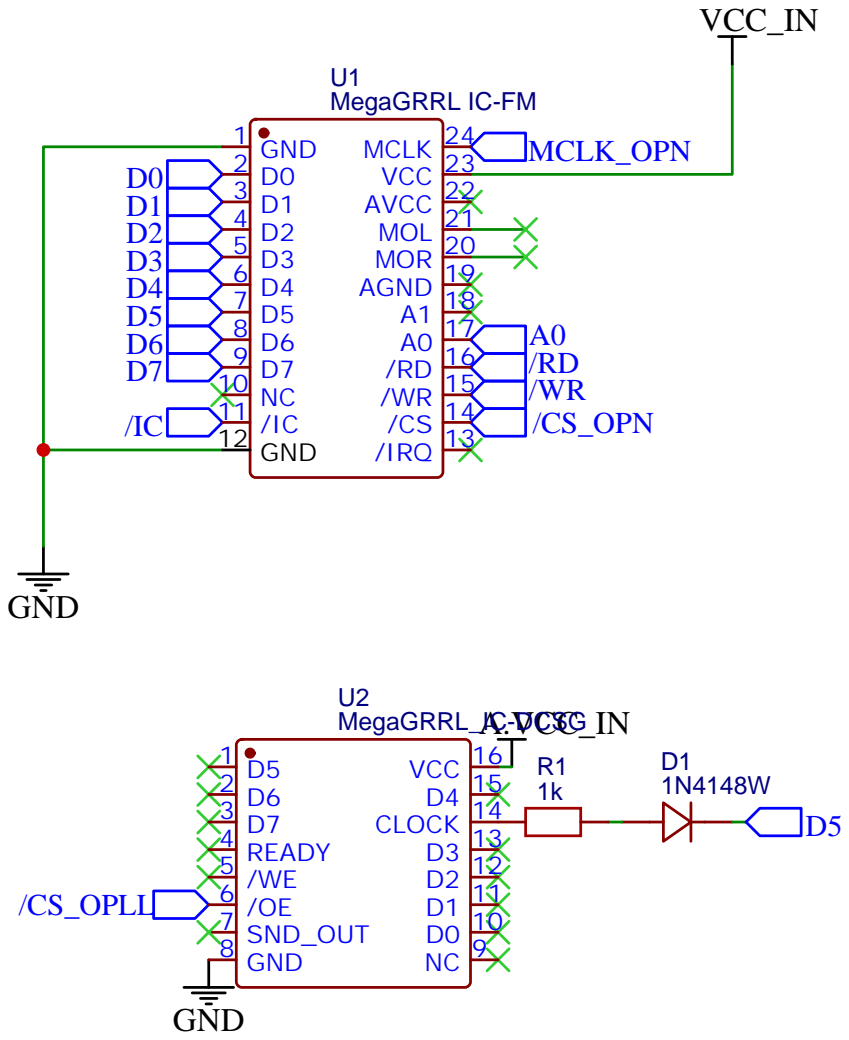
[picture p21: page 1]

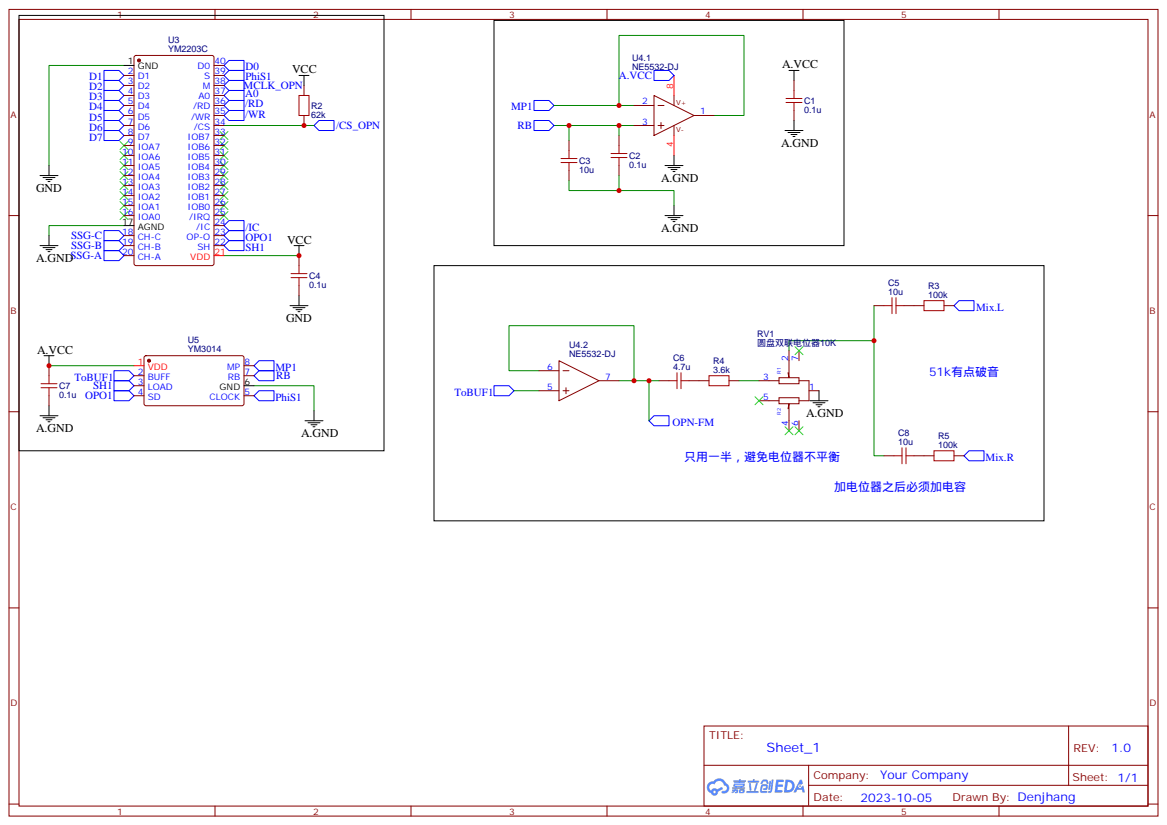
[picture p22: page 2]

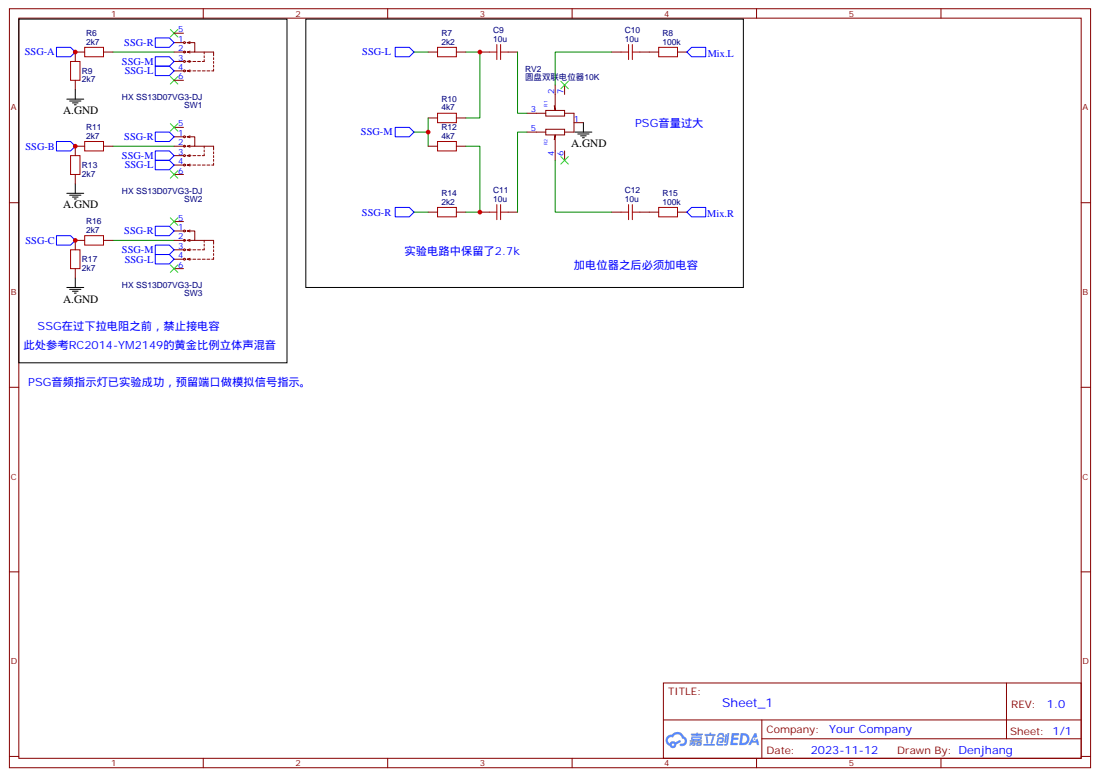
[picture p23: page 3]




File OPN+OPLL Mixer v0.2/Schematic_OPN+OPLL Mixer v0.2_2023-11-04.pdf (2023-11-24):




此处PSG-M电阻必须大，大阻值可用增强立体声效果
如果电阻太小，则LR混合，无立体声效果，或效果不明显





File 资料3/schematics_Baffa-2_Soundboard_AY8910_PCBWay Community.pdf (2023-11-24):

A

A


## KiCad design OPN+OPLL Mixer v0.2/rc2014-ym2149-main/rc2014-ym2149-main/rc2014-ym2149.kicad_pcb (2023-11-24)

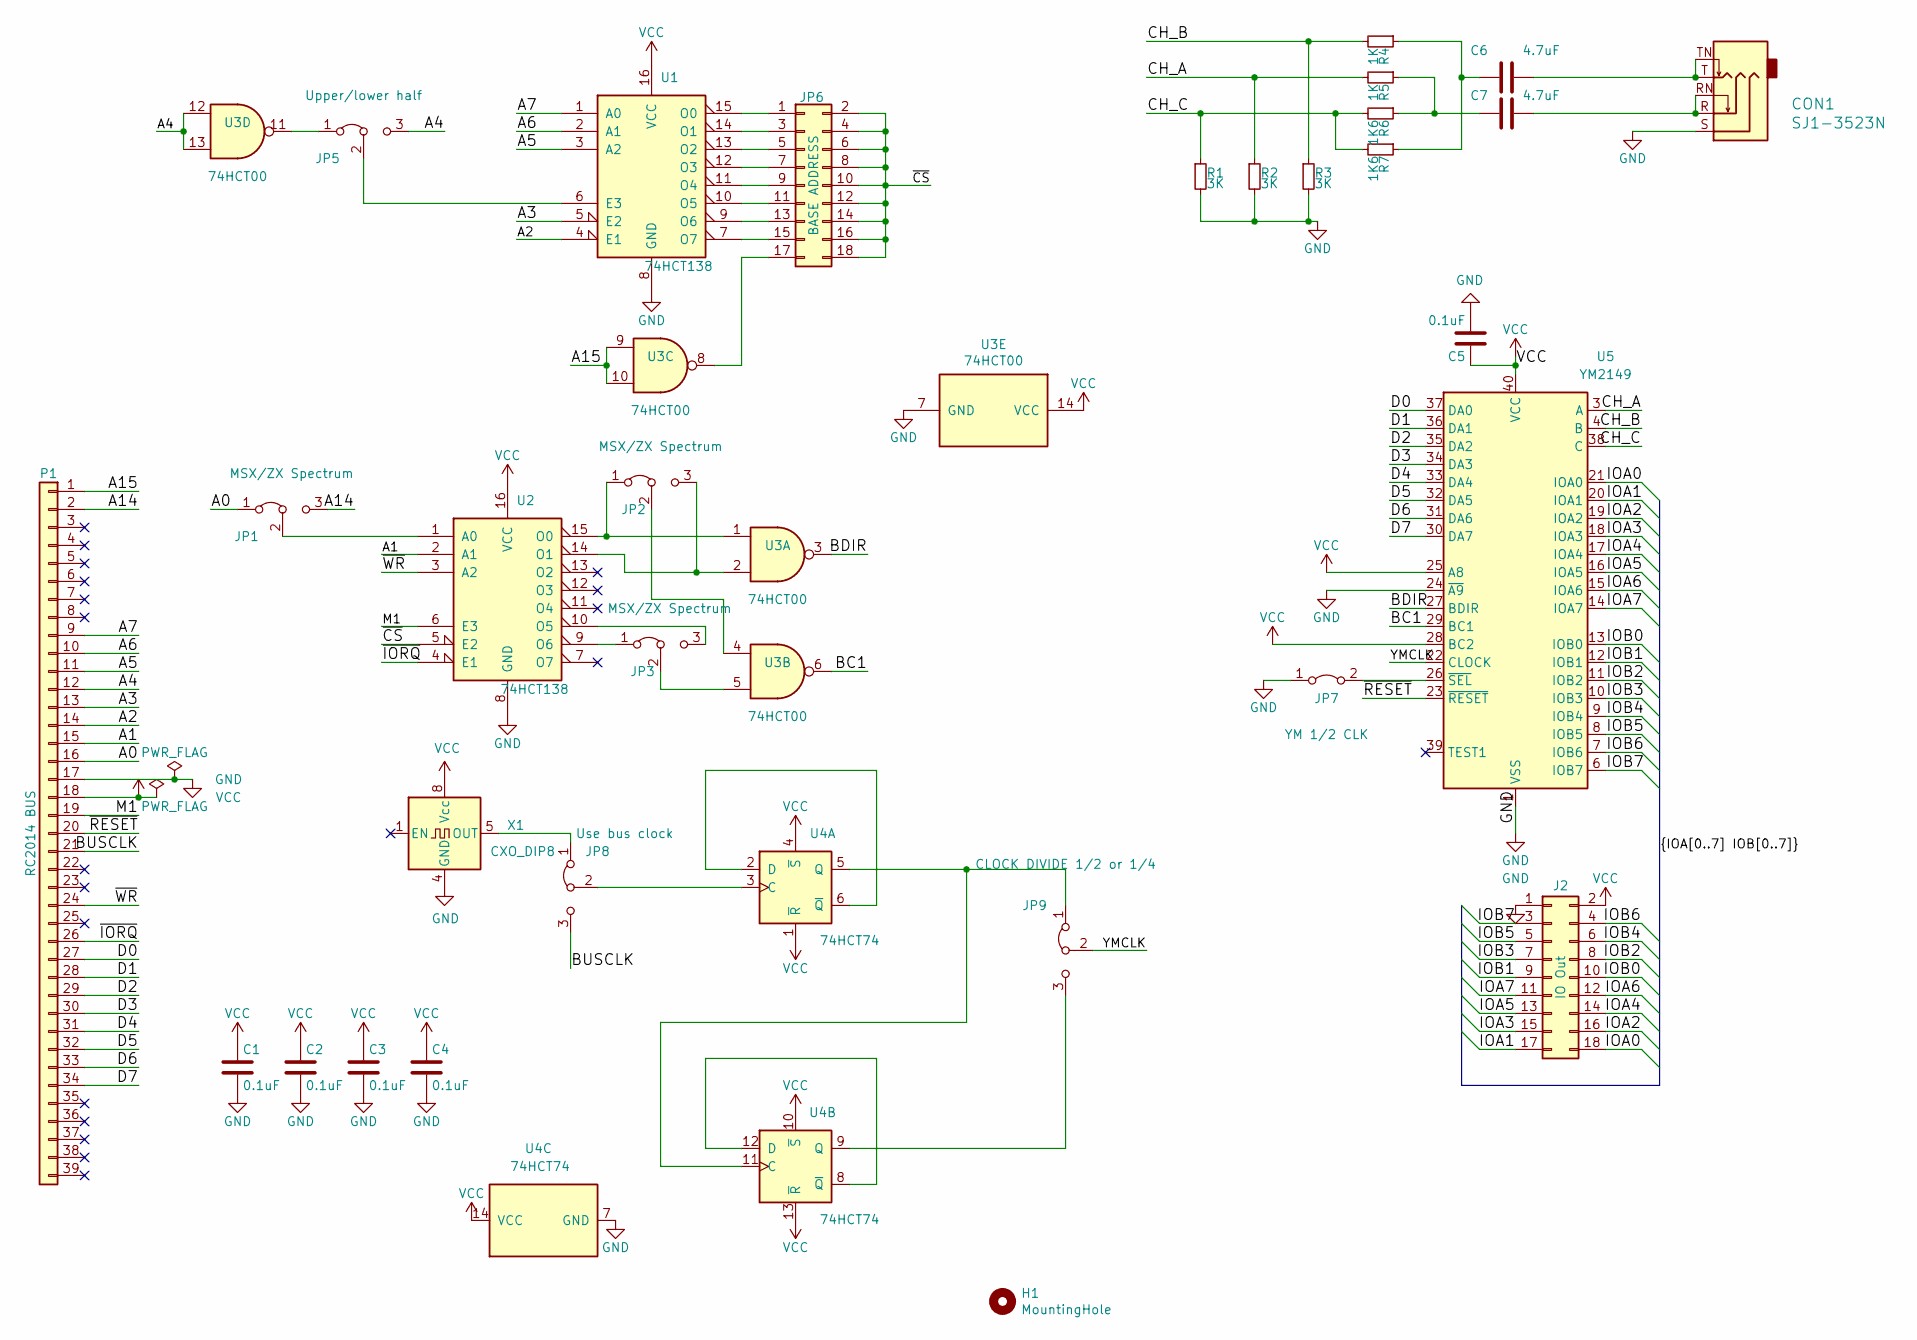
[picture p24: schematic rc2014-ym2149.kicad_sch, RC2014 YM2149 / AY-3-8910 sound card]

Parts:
C1, C2, C3, C4, C5: 0.1uF; C_Disc_D3.8mm_W2.6mm_P2.50mm
C6, C7: 4.7uF; CP_Radial_D6.3mm_P2.50mm
CON1: SJ1-3523N; Headphone_Jack_3.5mm_5_pin
H1: MountingHole; MountingHole_3.2mm_M3
J2: IO Out; PinHeader_2x09_P2.54mm_Vertical
JP1, JP2, JP3: MSX/ZX Spectrum; PinHeader_1x03_P2.54mm_Vertical
JP5: Upper/lower half; PinHeader_1x03_P2.54mm_Vertical
JP6: BASE ADDRESS; PinHeader_2x09_P2.54mm_Vertical
JP7: YM 1/2 CLK; PinHeader_1x02_P2.54mm_Vertical
JP8: Use bus clock; PinHeader_1x03_P2.54mm_Vertical
JP9: CLOCK DIVIDE 1/2 or 1/4; PinHeader_1x03_P2.54mm_Vertical
P1: RC2014 BUS; PinHeader_1x39_P2.54mm_Vertical
R1, R2, R3: 3K; R_Axial_DIN0207_L6.3mm_D2.5mm_P10.16mm_Horizontal
R4, R5: 1K; R_Axial_DIN0207_L6.3mm_D2.5mm_P10.16mm_Horizontal
R6, R7: 1K6; R_Axial_DIN0207_L6.3mm_D2.5mm_P10.16mm_Horizontal
U1, U2: 74HCT138; DIP-16_W7.62mm_Socket_LongPads
U3: 74HCT00; DIP-14_W7.62mm_Socket_LongPads
U4: 74HCT74; DIP-14_W7.62mm_Socket_LongPads
U5: YM2149; DIP-40_W15.24mm
X1: CXO_DIP8; Oscillator_DIP-8

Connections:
/A0: JP1.1 (A), P1.16
/A1: P1.15, U2.2 (A1)
/A2: P1.14, U1.4 (E1)
/A3: P1.13, U1.5 (E2)
/A4: JP5.3 (B), P1.12, U3.12, U3.13
/A5: P1.11, U1.3 (A2)
/A6: P1.10, U1.2 (A1)
/A7: P1.9, U1.1 (A0)
/A14: JP1.3 (B), P1.2
/A15: P1.1, U3.9, U3.10
/BC1: U3.6, U5.29 (BC1)
/BDIR: U3.3, U5.27 (BDIR)
/BUSCLK: JP8.3 (B), P1.21
/CH_A: R2.1, R5.2, U5.3 (A)
/CH_B: R3.1, R4.2, U5.4 (B)
/CH_C: R1.1, R6.2, R7.2, U5.38 (C)
/D0: P1.27, U5.37 (DA0)
/D1: P1.28, U5.36 (DA1)
/D2: P1.29, U5.35 (DA2)
/D3: P1.30, U5.34 (DA3)
/D4: P1.31, U5.33 (DA4)
/D5: P1.32, U5.32 (DA5)
/D6: P1.33, U5.31 (DA6)
/D7: P1.34, U5.30 (DA7)
/IOA0: J2.18, U5.21 (IOA0)
/IOA1: J2.17, U5.20 (IOA1)
/IOA2: J2.16, U5.19 (IOA2)
/IOA3: J2.15, U5.18 (IOA3)
/IOA4: J2.14, U5.17 (IOA4)
/IOA5: J2.13, U5.16 (IOA5)
/IOA6: J2.12, U5.15 (IOA6)
/IOA7: J2.11, U5.14 (IOA7)
/IOB0: J2.10, U5.13 (IOB0)
/IOB1: J2.9, U5.12 (IOB1)
/IOB2: J2.8, U5.11 (IOB2)
/IOB3: J2.7, U5.10 (IOB3)
/IOB4: J2.6, U5.9 (IOB4)
/IOB5: J2.5, U5.8 (IOB5)
/IOB6: J2.4, U5.7 (IOB6)
/IOB7: J2.3, U5.6 (IOB7)
/M1: P1.19, U2.6 (E3)
/YMCLK: JP9.2 (C), U5.22 (CLOCK)
/~CS: JP6.2, JP6.4, JP6.6, JP6.8, JP6.10, JP6.12, JP6.14, JP6.16, JP6.18, U2.5 (E2)
/~IORQ: P1.26, U2.4 (E1)
/~RESET: P1.20, U5.23 (~RESET)
/~WR: P1.24, U2.3 (A2)
GND: C1.2, C2.2, C3.2, C4.2, C5.2, CON1.S, J2.1, JP7.1 (A), P1.17, R1.2, R2.2, R3.2, U1.8 (GND), U2.8 (GND), U3.7 (GND), U4.7 (GND), U5.1 (VSS), U5.24 (~A9), X1.4 (GND)
unnamed: C6.1, R4.1, R7.1
unnamed: C6.2, CON1.T, CON1.TN
unnamed: C7.1, R5.1, R6.1
unnamed: C7.2, CON1.R, CON1.RN
unnamed: JP1.2 (C), U2.1 (A0)
unnamed: JP2.1 (A), U2.15 (O0), U3.1
unnamed: JP2.2 (C), U3.4
unnamed: JP2.3 (B), U2.14 (O1), U3.2
unnamed: JP3.1 (A), U2.9 (O6)
unnamed: JP3.2 (C), U3.5
unnamed: JP3.3 (B), U2.10 (O5)
unnamed: JP5.1 (A), U3.11
unnamed: JP5.2 (C), U1.6 (E3)
unnamed: JP6.1, U1.15 (O0)
unnamed: JP6.3, U1.14 (O1)
unnamed: JP6.5, U1.13 (O2)
unnamed: JP6.7, U1.12 (O3)
unnamed: JP6.9, U1.11 (O4)
unnamed: JP6.11, U1.10 (O5)
unnamed: JP6.13, U1.9 (O6)
unnamed: JP6.15, U1.7 (O7)
unnamed: JP6.17, U3.8
unnamed: JP7.2 (B), U5.26 (~SEL)
unnamed: JP8.1 (A), X1.5 (OUT)
unnamed: JP8.2 (C), U4.3 (C)
unnamed: JP9.1 (A), U4.5 (Q), U4.11 (C)
unnamed: JP9.3 (B), U4.9 (Q)
unnamed: U4.2 (D), U4.6 (~Q)
unnamed: U4.8 (~Q), U4.12 (D)
VCC: C1.1, C2.1, C3.1, C4.1, C5.1, J2.2, P1.18, U1.16 (VCC), U2.16 (VCC), U3.14 (VCC), U4.1 (~R), U4.4 (~S), U4.10 (~S), U4.13 (~R), U4.14 (VCC), U5.25 (A8), U5.28 (BC2), U5.40 (VCC), X1.8 (Vcc)

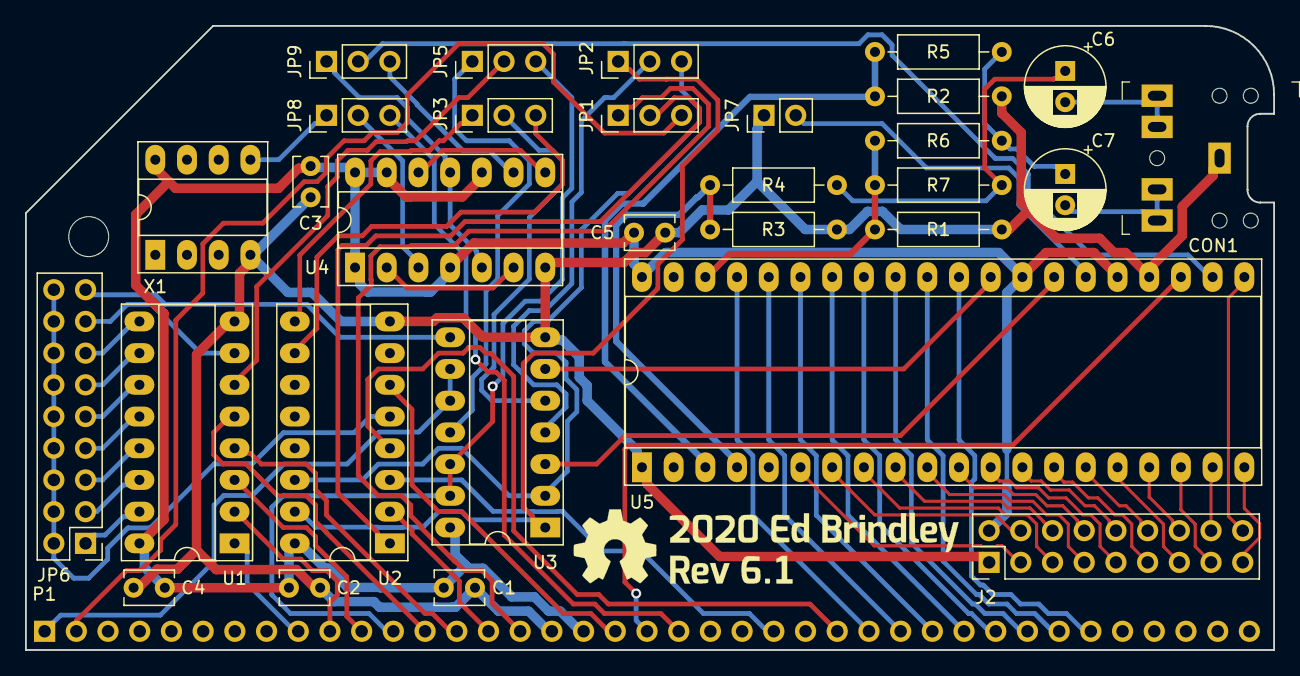
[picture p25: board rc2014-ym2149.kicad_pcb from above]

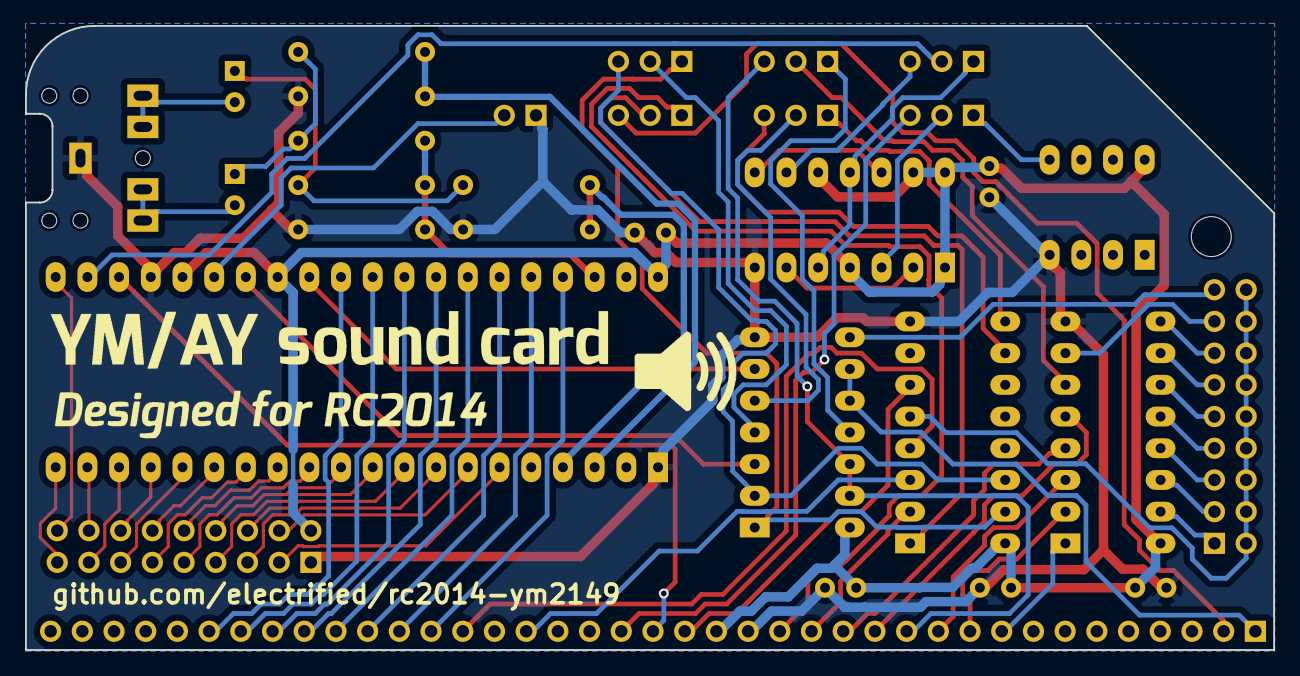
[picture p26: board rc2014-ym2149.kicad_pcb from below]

Board: 2 copper layers, 100.0 x 50.0 mm, 35 parts (2 on the bottom side), 77 nets.

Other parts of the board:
G1: LOGO; ym_text2
G2: LOGO; designed_for_rc2014
G5: LOGO; rev61

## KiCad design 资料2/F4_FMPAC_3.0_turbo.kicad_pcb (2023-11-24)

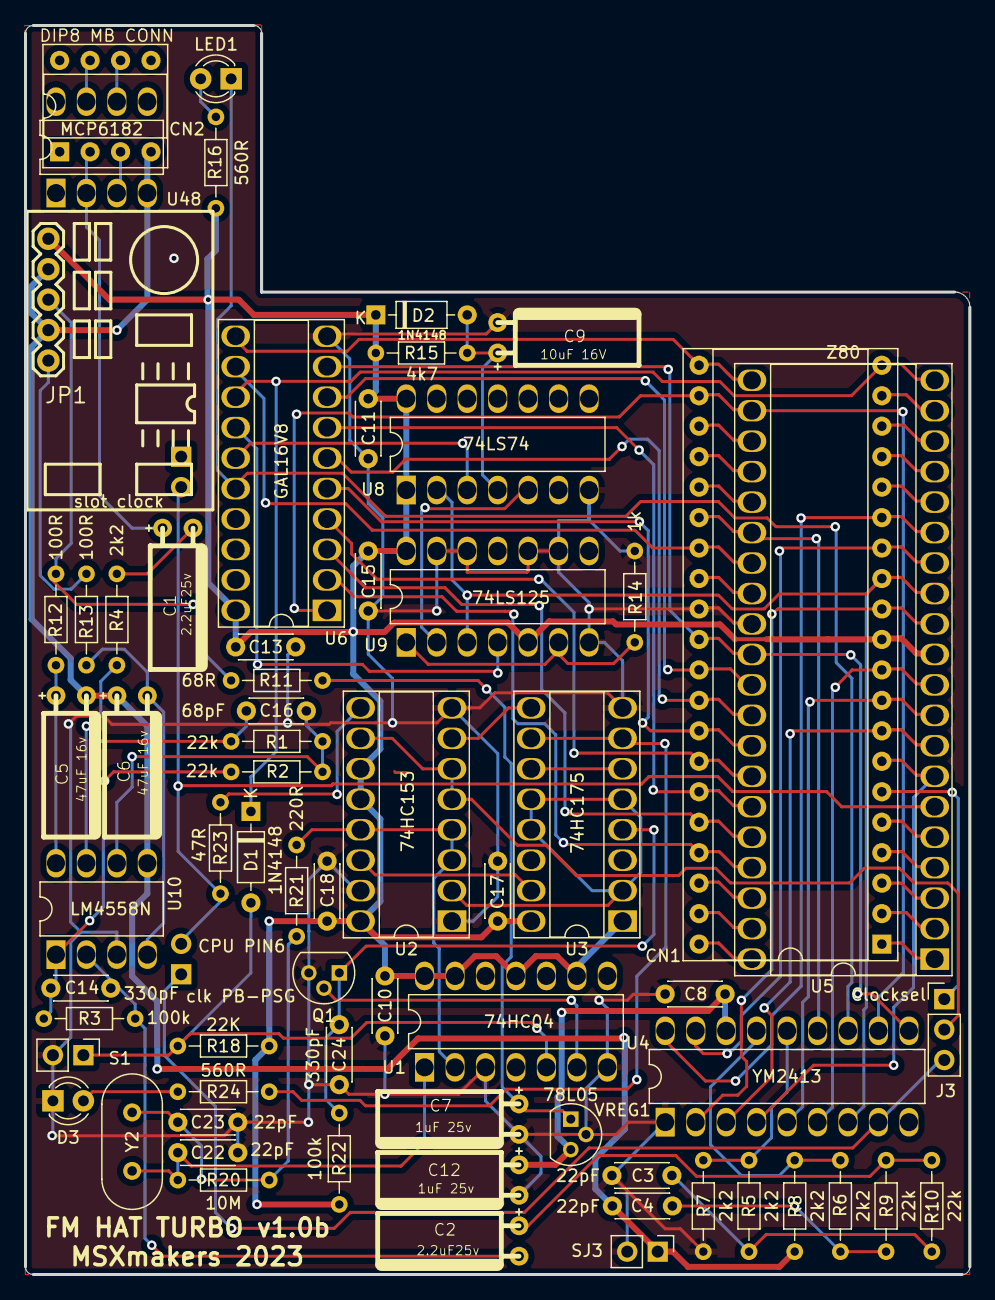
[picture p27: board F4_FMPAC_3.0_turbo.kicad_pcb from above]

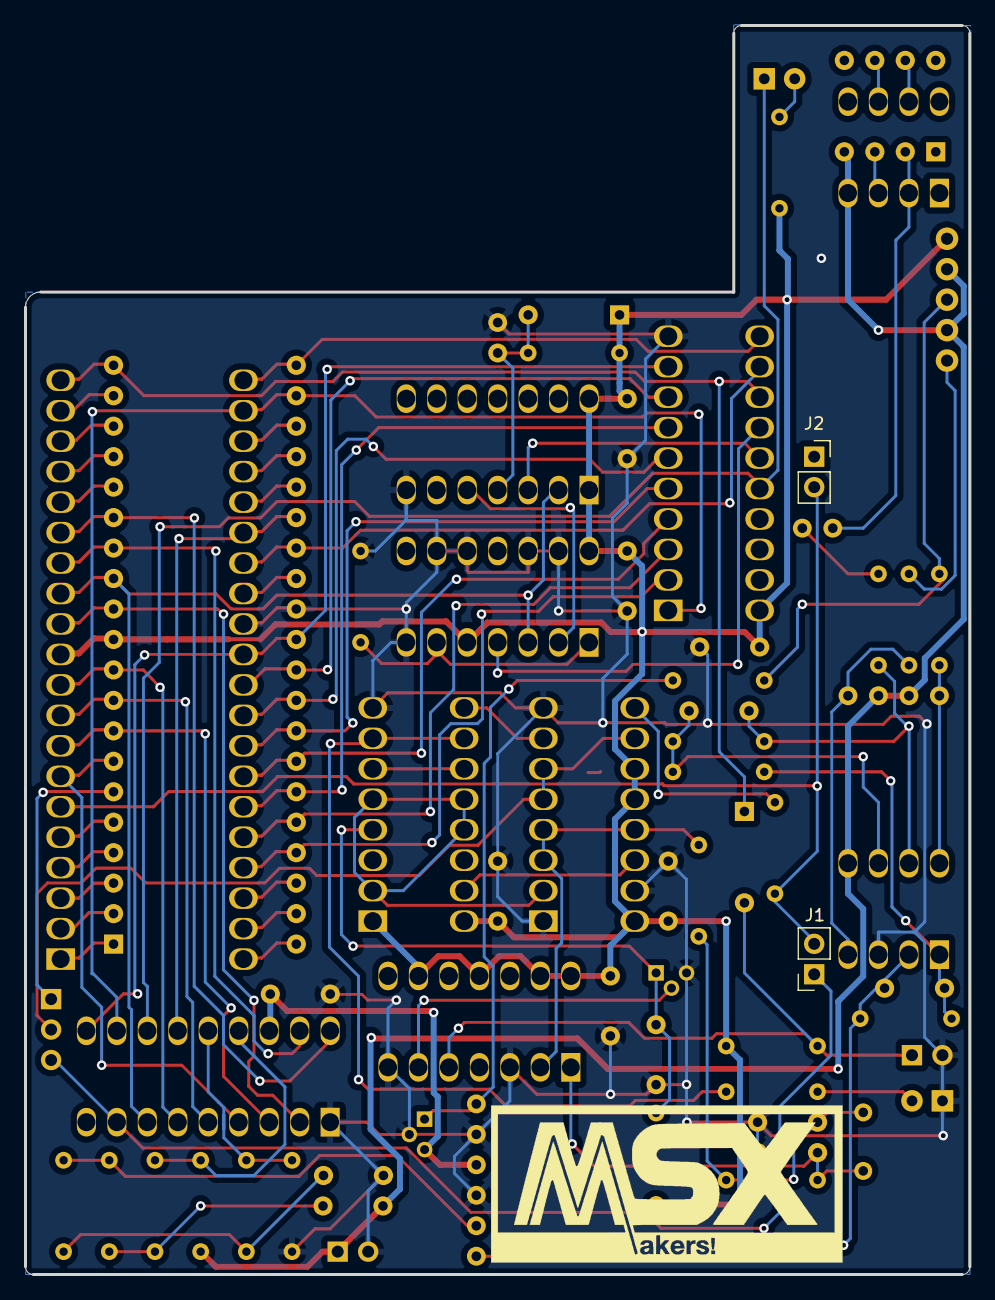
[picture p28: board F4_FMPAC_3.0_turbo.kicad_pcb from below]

Board: 2 copper layers, 78.7 x 104.1 mm, 68 parts (2 on the bottom side), 84 nets.

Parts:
C1, C2: 2.2uF25v; CP_tumbado
C3, C4, C22, C23: 22pF; C_Disc_D4.3mm_W1.9mm_P5.00mm
C5, C6: 47uF 16v; CP_tumbado
C7, C12: 1uF 25v; CP_tumbado
C8, C10, C11, C13, C15, C17, C18: 100nF; C_Disc_D4.3mm_W1.9mm_P5.00mm
C9: 10uF 16V; CP_tumbado
C14, C24: 330pF; C_Disc_D4.3mm_W1.9mm_P5.00mm
C16: 68pF; C_Disc_D4.3mm_W1.9mm_P5.00mm
CN1: DIP40 MB CONN; DIP-40_W15.24mm_Socket
CN2: DIP8 MB CONN; DIP-8_W7.62mm_Socket
D1, D2: 1N4148; D_DO-35_SOD27_P7.62mm_Horizontal
D3: LED; LED_D3.0mm
J1: clock_sel MB/JP; PinSocket_1x02_P2.54mm_Vertical
J2: slot clock; PinSocket_1x02_P2.54mm_Vertical
J3: Clocksel; PinHeader_1x03_P2.54mm_Vertical
JP1: Conn_01x05; Eletechsup_DD1718PA
LED1: LED 3mm; LED_D3.0mm
Q1: BS170; TO-92L
R1, R2, R9, R10: 22k; R_Axial_DIN0204_L3.6mm_D1.6mm_P7.62mm_Horizontal
R3, R22: 100k; R_Axial_DIN0204_L3.6mm_D1.6mm_P7.62mm_Horizontal
R4, R5, R6, R7, R8: 2k2; R_Axial_DIN0204_L3.6mm_D1.6mm_P7.62mm_Horizontal
R11: 68R; R_Axial_DIN0204_L3.6mm_D1.6mm_P7.62mm_Horizontal
R12, R13: 100R; R_Axial_DIN0204_L3.6mm_D1.6mm_P7.62mm_Horizontal
R14: 1k; R_Axial_DIN0204_L3.6mm_D1.6mm_P7.62mm_Horizontal
R15: 4k7; R_Axial_DIN0204_L3.6mm_D1.6mm_P7.62mm_Horizontal
R16, R24: 560R; R_Axial_DIN0204_L3.6mm_D1.6mm_P7.62mm_Horizontal
R18: 22K; R_Axial_DIN0204_L3.6mm_D1.6mm_P7.62mm_Horizontal
R20: 10M; R_Axial_DIN0204_L3.6mm_D1.6mm_P7.62mm_Horizontal
R21: 220R; R_Axial_DIN0204_L3.6mm_D1.6mm_P7.62mm_Horizontal
R23: 47R; R_Axial_DIN0204_L3.6mm_D1.6mm_P7.62mm_Horizontal
S1: turbo_on; PinHeader_1x02_P2.54mm_Vertical
SJ3: SJ; PinHeader_1x02_P2.54mm_Vertical
U1: 74HC04; DIP-14c_W7.62mm_LongPads
U2: 74HC153; DIP-16c_W7.62mm_Socket_LongPads
U3: 74HC175; DIP-16c_W7.62mm_Socket_LongPads
U4: YM2413; DIP-18c_W7.62mm_LongPads
U5: Z80; DIP-40c_W15.24mm_Socket_LongPads
U6: GAL16V8; DIP-20c_W7.62mm_Socket_LongPads
U8: 74LS74; DIP-14c_W7.62mm_LongPads
U9: 74LS125; DIP-14c_W7.62mm_LongPads
U10: LM4558N; DIP-8c_W7.62mm_LongPads
U48: MCP6182; DIP-8c_W7.62mm_LongPads
VREG1: 78L05; TO-92L
Y2: HighFreq; Crystal_HC49-U_Vertical

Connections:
+5V: C10.1, C11.1, C13.1, C15.1, C17.1, C18.1, CN1.11, D2.1 (K), JP1.1, R15.1, R16.2, R18.1, R22.1, U1.9, U1.11, U1.13, U1.14 (VCC), U2.11 (I1b), U2.12 (I2b), U2.16 (VCC), U3.1 (~Mr), U3.16 (VCC), U5.11 (VCC), U6.20 (VCC), U8.1 (~R), U8.14 (VCC), U9.5, U9.14 (VCC)
+12V: JP1.3, R11.2, R12.2
-12V: JP1.5, R13.2
/+5VREG: C8.2, C12.1, U4.16, VREG1.3 (OUT)
/A0: CN1.30, U4.10, U5.30 (A0), U6.9 (I9)
/A1: CN1.31, U5.31 (A1), U6.8 (I8)
/A2: CN1.32, U5.32 (A2), U6.6 (I6)
/A3: CN1.33, U5.33 (A3), U6.5 (I5)
/A4: CN1.34, U5.34 (A4), U6.4 (I4)
/A5: CN1.35, U5.35 (A5), U6.7 (I7)
/A6: CN1.36, U5.36 (A6), U6.3 (I3)
/A7: CN1.37, U5.37 (A7), U6.2 (I2)
/A8: CN1.38, U5.38 (A8)
/A9: CN1.39, U5.39 (A9)
/A10: CN1.40, U5.40 (A10)
/A11: CN1.1, U5.1 (A11)
/A12: CN1.2, U5.2 (A12)
/A13: CN1.3, U5.3 (A13)
/A14: CN1.4, U5.4 (A14)
/A15: CN1.5, U5.5 (A15)
/AMP: C1.1, CN2.2 (-), U48.2 (-)
/BUSAK: CN1.23, U5.23 (BUSAK)
/BUSRQ: CN1.25, U5.25 (BUSRQ)
/CLCK: J1.2, J2.2, R23.2, U5.6 (CLK)
/D0: CN1.14, U4.17, U5.14 (D0)
/D1: CN1.15, U4.18, U5.15 (D1)
/D2: CN1.12, U4.2, U5.12 (D2)
/D3: CN1.8, U4.3, U5.8 (D3)
/D4: CN1.7, U4.4, U5.7 (D4)
/D5: CN1.9, U4.5, U5.9 (D5)
/D6: CN1.10, U4.6, U5.10 (D6)
/D7: CN1.13, U4.7, U5.13 (D7), U8.2 (D), U9.3
/F4RD: U6.14 (IO6), U9.4
/F4WR: U6.15 (IO5), U8.3 (C)
/FMCS: LED1.1 (K), U4.12, U6.16 (IO4)
/HALT: CN1.18, U5.18 (HALT)
/INT: CN1.16, U5.16 (INT)
/IORQ: CN1.20, D1.1 (K), U5.20 (IORQ), U6.13 (IO7)
/M1: CN1.27, U5.27 (M1), U6.12 (IO8)
/MB_CLCK1: J1.1, J3.3, U4.8
/MB_CLCK2: CN1.6, J3.1
/MREQ: CN1.19, U5.19 (MREQ)
/NMI: CN1.17, U5.17 (NMI)
/RD: CN1.21, U5.21 (RD), U6.11 (I10/~OE)
/RFSH: CN1.28, U5.28 (RFSH)
/RST: CN1.26, U4.13, U5.26 (RESET)
/WAIT: CN1.24, U5.24 (WAIT)
/WR: CN1.22, U4.11, U5.22 (WR), U6.1 (I1/CLK)
GND: C3.1, C7.2, C8.1, C9.2, C10.2, C11.2, C12.2, C13.2, C15.2, C17.2, C18.2, C22.2, C23.2, C24.2, CN1.29, D3.1 (K), Q1.3 (S), R7.2, R14.1, S1.2, SJ3.2, U1.3, U1.7 (GND), U2.1 (Ea), U2.8 (GND), U2.15 (Eb), U3.8 (GND), U4.1, U5.29 (GND), U6.10 (GND), U8.7 (GND), U9.7 (GND), U9.9, U9.10, U9.12, U9.13, U10.3 (+IN), VREG1.2 (GND)
GND1: C4.2, C5.2, C6.1, CN2.4 (V-), JP1.2, JP1.4, R8.1, SJ3.1, U10.5 (+IN), U48.4 (V-)
unnamed: C1.2, R4.2
unnamed: C2.1, R9.2, R10.2
unnamed: C3.2, R5.2, R10.1
unnamed: C4.1, R6.2, R9.1
unnamed: C5.1, R12.1, U10.8 (V+)
unnamed: C6.2, R13.1, U10.4 (V-)
unnamed: C7.1, R11.1, VREG1.1 (IN)
unnamed: C9.1, D2.2 (A), R15.2, U8.4 (~S)
unnamed: C2.2, C14.1, R3.1, U10.2 (-IN)
unnamed: C14.2, R2.2, R3.2, U10.1 (OUT)
unnamed: C16.1, R1.1, R2.1, U10.6 (-IN)
unnamed: C16.2, R1.2, R4.1, U10.7 (OUT)
unnamed: C22.1, R20.1, U1.1, Y2.1
unnamed: C23.1, R20.2, R21.1, Y2.2
unnamed: C24.1, Q1.1 (D), R22.2, U3.4 (D0)
unnamed: CN2.3 (+), U48.3 (+)
unnamed: CN2.6, U48.6
unnamed: CN2.7 (V+), U48.7 (V+)
unnamed: D1.2 (A), R18.2, S1.1, U1.5
unnamed: D3.2 (A), R24.2
unnamed: J3.2, U2.5 (I1a), U2.6 (I0a), U2.10 (I0b)
unnamed: LED1.2 (A), R16.1
unnamed: Q1.2 (G), U1.6
unnamed: R5.1, R7.1, U4.14
unnamed: R6.1, R8.2, U4.15
unnamed: R14.2, U9.1, U9.6
unnamed: R21.2, U1.2, U2.3 (I3a), U2.4 (I2a), U2.13 (I3b)
unnamed: R23.1, U2.9 (Zb)
unnamed: R24.1, U3.7 (Q1), U3.10 (Q2)
unnamed: U2.2 (S1), U3.2 (Q0), U3.5 (D1), U3.12 (D2), U3.13 (D3)
unnamed: U2.7 (Za), U3.9 (Cp)
unnamed: U2.14 (S0), U3.15 (Q3)
unnamed: U3.6 (~Q1), U3.11 (~Q2)
unnamed: U8.5 (Q), U9.2
